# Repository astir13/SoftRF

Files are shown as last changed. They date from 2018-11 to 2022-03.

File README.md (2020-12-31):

# SoftRF 
Multifunctional DIY IoT-based general aviation proximity awareness system, forked from http://github.com/lyusupov/SoftRF. This fork only supports the prime mkII hardware and provides some extra modifications to allow for following features:

# Features on top of SoftRF prime mkII
* external 12V powered (has a power supply)
* external equipment connected through 9-pin D-Sub connector
* power switch management that allows power control operation even if the SoftRF is hidden behind the instrument panel
* auto power off when on ground and no external power supplied
* supports NMEA devices like Flarm LED/LX devices through RS-232

# Documentation
* [User Manual](https://github.com/astir13/SoftRF/tree/master/documents/usermanual/binaries)
* Software
    * Firmware
        * [Binary Releases](https://github.com/astir13/SoftRF/wiki/Updates)
        * [Source](https://github.com/astir13/SoftRF/tree/master/software/firmware/source)
* Hardware
You need:
    * 1x TT-GO T-Beam v1.1 board with OLED display, like https://www.aliexpress.com/item/33050391850.html?spm=a2g0s.9042311.0.0.27424c4dU9WiWD
    * 1x RS-232/UART converter, like https://www.aliexpress.com/item/4000189810712.html?spm=a2g0s.9042311.0.0.27424c4dQ6D88f
    * 1x DC-DC 12V to 5V/3A converter as power supply, like https://www.aliexpress.com/item/32826540392.html?spm=a2g0s.9042311.0.0.27424c4dbbq0Ht
    * a chassis, 3D printed: https://www.thingiverse.com/thing:4704154/
    * some hot-glue to fix wires and components on the T-beam to be more vibration resistant in the aviation environment
    * 4 small plastc screws
    * some wires
    * a protected Li-Ion battery, size 18650, 2600mAh or better, with integrated battery management system to give added security
    * a 9-pin sub-d female and male connector for soldering with matching srews to secure the corresponding counterpart with
    * a power ON-OFF-(ON) switch, like MS500D from Myiama Parts, e.g. https://www.reichelt.de/kippschalter-6a-125vac-1x-ein-aus-ein--ms-500d-p13156.html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
* Extras
    * see https://github.com/lyusupov/SoftRF

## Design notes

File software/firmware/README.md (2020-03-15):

## WebUI



## License

Copyright (C) 2016-2020 Linar Yusupov <linar.r.yusupov@gmail.com>

This program is free software: you can redistribute it and/or modify
it under the terms of the GNU General Public License as published by
the Free Software Foundation, either version 3 of the License, or
(at your option) any later version.

This program is distributed in the hope that it will be useful,
but WITHOUT ANY WARRANTY; without even the implied warranty of
MERCHANTABILITY or FITNESS FOR A PARTICULAR PURPOSE.  See the
GNU General Public License for more details.

You should have received a copy of the GNU General Public License
along with this program.  If not, see <http://www.gnu.org/licenses/>.

## Credits

 * Arduino core for ESP8266 is developed/supported by **ESP8266 Community** (support-esp8266@esp8266.com)
 * AVR/Arduino nRF905 Library/Driver is developed by **Zak Kemble**, contact@zakkemble.co.uk
 * flarm_decode is developed by **Stanislaw Pusep**, http://github.com/creaktive
 * Arduino Time Library is developed by **Paul Stoffregen**, http://github.com/PaulStoffregen
 * "Aircraft" and MAVLink Libraries are developed by **Andy Little**
 * TinyGPS++ and PString Libraries are developed by **Mikal Hart**
 * Adafruit NeoPixel Library is developed by **Phil Burgess**, **Michael Miller** and others
 * TrueRandom Library is developed by **Peter Knight**
 * IBM LMIC framework is maintained by **Matthijs Kooijman**
 * ESP8266FtpServer is developed by **David Paiva**
 * Lib_crc is developed by **Lammert Bies**
 * OGN library is developed by **Pawel Jalocha**
 * NMEA library is developed by **Timur Sinitsyn**, **Tobias Simon**, **Ferry Huberts**
 * ADS-B encoder C++ library is developed by **yangbinbin** (yangbinbin_ytu@163.com)
 * Arduino Core for ESP32 is developed by **Hristo Gochkov**
 * Adafruit BMP085 library is developed by **Limor Fried** and **Ladyada**
 * Adafruit BMP280 library is developed by **Kevin Townsend**
 * Adafruit MPL3115A2 library is developed by **Limor Fried** and **Kevin Townsend**
 * U8g2 monochrome LCD, OLED and eInk library is developed by **Oliver Kraus**
 * NeoPixelBus library is developed by **Michael Miller**
 * jQuery library is developed by **JS Foundation**
 * EGM96 data is developed by **XCSoar team**
 * BCM2835 C library is developed by **Mike McCauley**
 * SimpleNetwork library is developed by **Dario Longobardi**
 * ArduinoJson library is developed by **Benoit Blanchon**
 * Flashrom library is part of the **flashrom.org project**
 * Arduino Core for TI CC13X0 is developed by **Energia team**
 * EasyLink library is developed by **Robert Wessels** and **Tony Cave**
 * Dump978 library is developed by **Oliver Jowett**
 * FEC library is developed by **Phil Karn**
 * AXP20X, BMA423, FT5206 and PCF8563 libraries are developed by **Lewis He**
 * GxEPD2 library is developed by **Jean-Marc Zingg**
 * Adafruit SSD1306 and GFX libraries are developed by **Adafruit Industries**
 * GDL90 decoder is developed by **Ryan David**
 * Sqlite3 Arduino library for ESP32 is developed by **Arundale Ramanathan**
 * FLN/OGN aircrafts data is courtesy of **FlarmNet/GliderNet**
 * ESP32 I2S WAV player example is developed by **Tuan Nha**
 * AceButton library is developed by **Brian Park**
 * Arduino Core for STM32 is developed by **Frederic Pillon**
 * Python IGC format encoder is developed by **Tobias Bieniek**
 * port of MicroPython for ESP32 is developed by **Boris Lovosevic**
 * ESP32 BT SPP library is developed by **Evandro Copercini**
 * TFT library is developed by **Bodmer**

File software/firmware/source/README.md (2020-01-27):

# SoftRF firmware build instructions

[NodeMCU](https://github.com/lyusupov/SoftRF/tree/master/software/firmware/source#nodemcu)<br>
[ESP32](https://github.com/lyusupov/SoftRF/tree/master/software/firmware/source#esp32)<br>
[Raspberry Pi](https://github.com/lyusupov/SoftRF/tree/master/software/firmware/source#raspberry-pi)<br>
[CC13XX](https://github.com/lyusupov/SoftRF/tree/master/software/firmware/source#cc13xx)<br>
[STM32](https://github.com/lyusupov/SoftRF/tree/master/software/firmware/source#stm32)<br>

<br>

## NodeMCU

1. Follow [these official instructions](https://github.com/esp8266/Arduino#installing-with-boards-manager)
  to install Arduino IDE and latest Arduino ESP8266 Core
2. Become familiar with IDE and **NodeMCU** by building and uploading of a basic **Blink** sketch:<br>

    _File_ -> _Examples_ -> _ESP8266_ -> _Blink_ <br>

    then<br>

    _Sketch_ -> _Upload_

3. When you are done with the lesson, close your **Arduino** application
4. open ``<My Documents>`` (Windows) or ``<Home>`` (Linux) directory
5. create **Arduino** sub-directory
6. transfer full content of **SoftRF** and **libraries** GitHub folders into the sub-directory:

    [SoftRF](https://github.com/lyusupov/SoftRF/tree/master/software/firmware/source/SoftRF) &nbsp;&nbsp;**-->** ``<My Documents>``/Arduino/SoftRF <br>
    [libraries](https://github.com/lyusupov/SoftRF/tree/master/software/firmware/source/libraries) **-->** ``<My Documents>``/Arduino/libraries <br>

7. start **Arduino** application again
8. open **SoftRF** sketch from _File_ -> _Open_ menu
9. Select _Tools_ -> _Board_ -> _NodeMCU_ _1.0_
10. in _Tools_ -> _lwIP Variant_  -> _v2 Higher Bandwidth_
11. _Sketch_ -> _Upload_

## ESP32

1. Follow [these official instructions](https://github.com/espressif/arduino-esp32/blob/master/docs/arduino-ide/boards_manager.md)
  to install Arduino IDE and [latest **stable** Arduino ESP32 Core](https://github.com/espressif/arduino-esp32/releases/tag/1.0.4) (1.0.4)
2. Become familiar with IDE and **DoIt ESP32 DevKit** by building and uploading of a basic **Blink** sketch:<br>
```
int ledPin = 2; // use pin 14 for TTGO T-Beam rev.05 or higher   

void setup()
{
    pinMode(ledPin, OUTPUT);
    Serial.begin(115200);
}

void loop()
{
    Serial.println("Hello, world!");
    digitalWrite(ledPin, HIGH);
    delay(500);
    digitalWrite(ledPin, LOW);
    delay(500);
}
```

3. When you are done with the lesson, close your **Arduino** application
4. open ``<My Documents>`` (Windows) or ``<Home>`` (Linux) directory
5. create **Arduino** sub-directory
6. transfer full content of **SoftRF** and **libraries** GitHub folders into the sub-directory:

    [SoftRF](https://github.com/lyusupov/SoftRF/tree/master/software/firmware/source/SoftRF) &nbsp;&nbsp;**-->** ``<My Documents>``/Arduino/SoftRF <br>
    [libraries](https://github.com/lyusupov/SoftRF/tree/master/software/firmware/source/libraries) **-->** ``<My Documents>``/Arduino/libraries <br>

<!-- 7. take **libbt.a** binary from [this location](https://github.com/lyusupov/SoftRF/tree/master/software/firmware/binaries/ESP32/misc)<br>
    and overwrite existing one in ``<My Documents>``/Arduino/hardware/espressif/esp32/tools/sdk/lib -->
7. start **Arduino** application again
8. open **SoftRF** sketch from _File_ -> _Open_ menu
9. Select _Tools_ -> _Board_ ->  _ESP32_ _Dev_ _Module_
10. Select _Tools_ -> _Flash_ _Mode_ ->  _DIO_
11. Select _Tools_ -> _Flash_ _Size_ ->  _4MB_
12. Select _Tools_ -> _Partition_ _Scheme_ ->  _Minimal_ _SPIFFS_
13. Select _Tools_ -> _Flash_ _Frequency_ ->  _80MHz_
14. Select _Tools_ -> _CPU_ _Frequency_ ->  _80MHz_
15. Select _Tools_ -> _PSRAM_ ->  _Enabled_
16. _Sketch_ -> _Upload_

<br>

## Raspberry Pi

Although CLI application's source code for Raspberry Edition is located [at the same place](https://github.com/lyusupov/SoftRF/tree/master/software/firmware/source)<br> 
and is shared with other SoftRF platforms - build instructions for the code are different.

This build has to be done on a Raspberry Pi host.<br>
A known good Raspbian OS version that fits for this purpose is "Stretch".<br>
Make sure that basic development packages (such as: binutils, g++, GNU make & etc) are installed.<br>

1. transfer full content of **SoftRF** and **libraries** GitHub folders into a temporary build directory:

    [SoftRF](https://github.com/lyusupov/SoftRF/tree/master/software/firmware/source/SoftRF) &nbsp;&nbsp;**-->** ``<your path>``/SoftRF <br>
    [libraries](https://github.com/lyusupov/SoftRF/tree/master/software/firmware/source/libraries) **-->** ``<your path>``/libraries <br>

2. change directory on ``<your path>``/SoftRF and execute **make** as follows:<br>

```
pi@raspberrypi: $ make -f Makefile.RPi
(cd ../libraries/bcm2835/src/../ ; ./configure ; make)
checking for a BSD-compatible install... /usr/bin/install -c
checking whether build environment is sane... yes
checking for a thread-safe mkdir -p... /bin/mkdir -p
checking for gawk... no

< ... skipped ... >
```

As a result of the build, two program binaries will become created:
- **SoftRF** - the program code designed to work with Raspberry Pi's primary SPI bus (SPI 0);
- **SoftRF-aux** - the same program but to run over auxiliary SPI bus (SPI 1).

<br>

## CC13XX

The firmware is to be built on a Linux x86_64 host.<br>
[Energia](http://energia.nu/download/) IDE has to be pre-installed first.<br>

1. open ``<Home>`` directory
2. create **Energia** sub-directory
3. transfer full content of **UATbridge**, **SoftRF** and **libraries** GitHub folders into the sub-directory:

    [UATbridge](https://github.com/lyusupov/SoftRF/tree/master/software/firmware/source/UATbridge) **-->** ``<Home>``/Energia/UATbridge <br>
    [SoftRF](https://github.com/lyusupov/SoftRF/tree/master/software/firmware/source/SoftRF) &nbsp;&nbsp;&nbsp;&nbsp;&nbsp;&nbsp;**-->** ``<Home>``/Energia/SoftRF <br>
    [libraries](https://github.com/lyusupov/SoftRF/tree/master/software/firmware/source/libraries) &nbsp;&nbsp;&nbsp;&nbsp;**-->** ``<Home>``/Energia/libraries <br>

4. change directory on ``<Home>``/Energia/UATbridge
5. create all necessary symbolic links by doing **make links**:

```
$ make links
Creating symlink Platform_CC13XX.cpp  -->  ../SoftRF/Platform_CC13XX.cpp
Creating symlink SoCHelper.cpp  -->  ../SoftRF/SoCHelper.cpp
Creating symlink RFHelper.cpp  -->  ../SoftRF/RFHelper.cpp
Creating symlink GNSSHelper.cpp  -->  ../SoftRF/GNSSHelper.cpp

< ... skipped ... >
```

6. start **Energia** application
7. open **UATbridge** sketch from _File_ -> _Open_ menu
8. [install support](http://energia.nu/guide/boards/) for TI CC13XX familiy with _Tools_ -> _Board_ ->  _Boards_ _Manager..._
9. Select _Tools_ -> _Board_ ->  _LaunchPad_ _w/_ _CC1310_ _EMT_ _(48MHz)_
10. Select _Tools_ -> _Port_ ->  ``<your XDS110 port device name>``
11. Select _Tools_ -> _Programmer_ ->  _dslite_
12. try to build and upload using _Sketch_ -> _Upload_

12a. or, to build the firmware using shell prompt, do:

```
$ make build
energia --verify --verbose-build UATbridge.ino
Picked up JAVA_TOOL_OPTIONS:
Loading configuration...
Initializing packages...
Preparing boards...
Verifying...

< ... skipped ... >
```

13a. inspect **/tmp** directory and sub-folders, take **UATbridge.ino.elf** file and use it with TI's **Uniflash** or **Flash Programmer 2**.<br>

14a. (Optional) if you want to use [**cc2538-bsl.py**](https://github.com/JelmerT/cc2538-bsl) tool to put the firmware into flash memory of CC1310 IC via **boot loader**, run **make ihex**:

```
$ make ihex

< ... skipped ... >
``` 

<br>

## STM32

The firmware is to be built on a Linux x86_64 host.<br>
You can try to build it under Windows but you will have to manually set all the file links in this case.<br>
You will also need to get and connect ST-LINK/V2 USB adapter in order to put the firmware into your hardware's flash memory.<br>

1. Follow [these official instructions](https://github.com/stm32duino/wiki/wiki/Getting-Started)
  to install Arduino IDE and [latest **stable** Arduino STM32 Core](https://github.com/stm32duino/Arduino_Core_STM32/releases/tag/1.8.0) (1.8.0)
2. open ``<Home>`` directory
3. create **Arduino** sub-directory
4. transfer full content of **Retro**, **SoftRF** and **libraries** GitHub folders into the sub-directory:

    [Retro](https://github.com/lyusupov/SoftRF/tree/master/software/firmware/source/Retro) &nbsp;&nbsp;&nbsp;**-->** ``<Home>``/Arduino/Retro <br>
    [SoftRF](https://github.com/lyusupov/SoftRF/tree/master/software/firmware/source/SoftRF) &nbsp;&nbsp;**-->** ``<Home>``/Arduino/SoftRF <br>
    [libraries](https://github.com/lyusupov/SoftRF/tree/master/software/firmware/source/libraries) **-->** ``<Home>``/Arduino/libraries <br>
5. change directory on ``<Home>``/Arduino/Retro
6. create all necessary symbolic links by doing **make links**:

```
$ make links
Creating symlink Platform_STM32.cpp  -->  ../SoftRF/Platform_STM32.cpp
Creating symlink SoCHelper.cpp  -->  ../SoftRF/SoCHelper.cpp
Creating symlink RFHelper.cpp  -->  ../SoftRF/RFHelper.cpp
Creating symlink GNSSHelper.cpp  -->  ../SoftRF/GNSSHelper.cpp

< ... skipped ... >
```

7. start **Arduino** application
8. open **Retro** sketch from _File_ -> _Open_ menu
9. For S76G:<br>
    &nbsp;&nbsp;&nbsp;&nbsp;&nbsp;&nbsp;Select _Tools_ -> _Board_ ->  _Nucleo_64_<br>
    &nbsp;&nbsp;&nbsp;&nbsp;&nbsp;&nbsp;Select _Tools_ -> _Optimize_ ->  _Fast_ _(-O1)_<br>
    &nbsp;&nbsp;&nbsp;&nbsp;&nbsp;&nbsp;Select _Tools_ -> _Board_ _part_ _number_ ->  _Nucleo_ _L073RZ_<br>
    For STM32F103C8 "Blue Pill":<br>
    &nbsp;&nbsp;&nbsp;&nbsp;&nbsp;&nbsp;Select _Tools_ -> _Board_ ->  _Generic_ _STM32F1_ _series_<br>
    &nbsp;&nbsp;&nbsp;&nbsp;&nbsp;&nbsp;Select _Tools_ -> _Optimize_ ->  _Smallest_ _(-Os_ _default)_<br>
    &nbsp;&nbsp;&nbsp;&nbsp;&nbsp;&nbsp;Select _Tools_ -> _Board_ _part_ _number_ ->  _BluePill_ _F103C8_ _(128k)_<br>
10. Select _Tools_ -> _C_ _Runtime_ _library_ ->  _Newlib_ _Nano_ _(default)_
11. Select _Tools_ -> _USB_ _speed_ _(if available)_ ->  _Low/Full_ _Speed_
12. For S76G "Dongle":<br>
    &nbsp;&nbsp;&nbsp;&nbsp;&nbsp;&nbsp;Select _Tools_ -> _USB_ _support_ _(if available)_ ->  _CDC_ _(generic_ _'Serial'_ _supersede_ _U(S)ART)_<br>
    &nbsp;&nbsp;&nbsp;&nbsp;&nbsp;&nbsp;Select _Tools_ -> _U(S)ART_ _support_ ->  _Enabled_ _(no_ _generic_ _'Serial')_<br>
    &nbsp;&nbsp;&nbsp;&nbsp;&nbsp;&nbsp;Select _Tools_ -> _Upload_ _method_ ->  _STM32CubeProgrammer_ _(DFU)_<br>
    &nbsp;&nbsp;&nbsp;&nbsp;&nbsp;&nbsp;Select _Tools_ -> _Port_ ->  ``<your Dongle's DFU device name>``<br>
    For S76G "SkyWatch" or STM32F103C8 "Blue Pill":<br>
    &nbsp;&nbsp;&nbsp;&nbsp;&nbsp;&nbsp;Select _Tools_ -> _USB_ _support_ _(if available)_ ->  _CDC_ _(no_ _generic_ _'Serial')_<br>
    &nbsp;&nbsp;&nbsp;&nbsp;&nbsp;&nbsp;Select _Tools_ -> _U(S)ART_ _support_ ->  _Enabled_ _(generic_ _'Serial')_<br>
    &nbsp;&nbsp;&nbsp;&nbsp;&nbsp;&nbsp;Select _Tools_ -> _Upload_ _method_ ->  _STM32CubeProgrammer_ _(SWD)_<br>
    &nbsp;&nbsp;&nbsp;&nbsp;&nbsp;&nbsp;Select _Tools_ -> _Port_ ->  ``<your ST-LINK/V2 port device name>``<br>
13. try to build and upload using _Sketch_ -> _Upload_

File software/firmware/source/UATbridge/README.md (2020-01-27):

## UAT Bridge

This folder contains source code of **UAT Bridge** firmware for Texas Instruments CC1310 RF SoC. <sup>1</sup><br>
The code is essential part of [SoftRF project](https://github.com/lyusupov/SoftRF).<br>

<sup>1</sup> - _mass production of CC1312R IC (direct successor of CC1310) is scheduled by TI on Q1 of 2019_.<br>
&nbsp;&nbsp;&nbsp; _Announced specs of the CC1312R are promising to make **1090ES** <sub>(worldwide ADS-B standard)</sub> reception possible as well_.<br>

## Purpose

Primary purpose of the **UAT bridge** is to receive ADS-B traffic information on UAT (978 MHz) aviation frequency,<br>
then to re-broadcast the data using one of supported RF ISM band protocols.<br>

For the list of the ISM protocols, please, read [SoftRF specs](https://github.com/lyusupov/SoftRF#compatibility-1).<br>

Traffic information is re-broadcasted at very low power setting, so reception coverage is limited to a close vicinity of
the aircraft, equipped with the **UAT Bridge**. Other aircrafts nearby, such as gliders on the grid, have a chance to receive the information as well.<br>  

The "**bridge**" is one-way only. No re-broadcasting from ISM band into aviation band (UAT) is allowed. Thus, it does **not** transmit anything on 978 MHz.<br>

For the benefit of most of pilots, **receiving device is not necessarily has to be one of [SoftRF](https://github.com/lyusupov/SoftRF) units**.<br>
Other make and models, such as SkyTraxx, OGN Tracker, PilotAware or FLARM should suffice.<br> 

## Hardware

DIY **UAT bridge** hardware consists of:
1. [SoftRF-UAT](https://github.com/lyusupov/UAT-test-signal#variant-2-advanced) main board, and
2. [SoftRF-LoRa](https://github.com/lyusupov/SoftRF/wiki/SoftRF-LoRa-module) daughterboard.

<br>
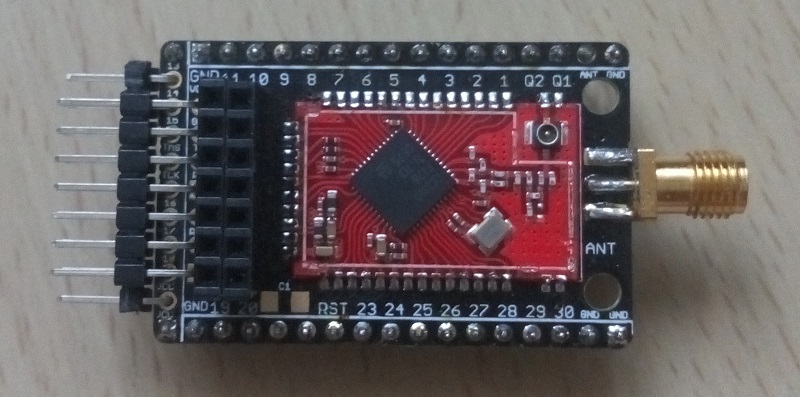
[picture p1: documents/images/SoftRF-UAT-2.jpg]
<br>
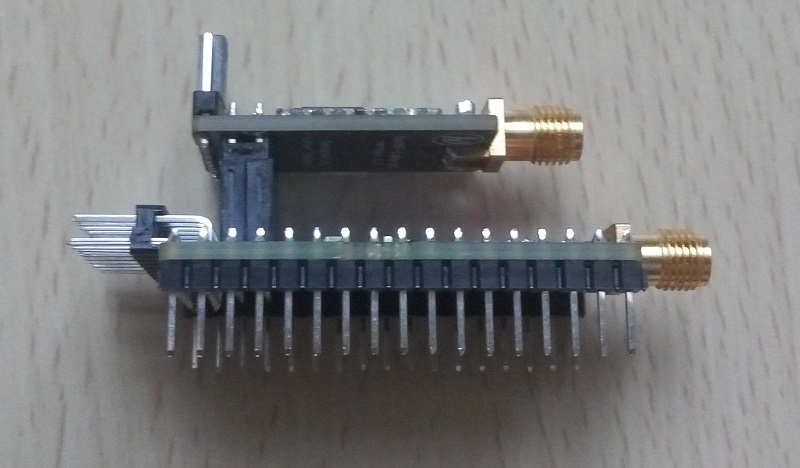
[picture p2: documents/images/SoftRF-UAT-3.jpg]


## Alternative use

The firmware auto-senses presence of connected [SoftRF-LoRa](https://github.com/lyusupov/SoftRF/wiki/SoftRF-LoRa-module) daughterboard.<br>
When the daughterboard is not attached - remaining [SoftRF-UAT](https://github.com/lyusupov/UAT-test-signal#variant-2-advanced) board fallbacks into **UAT Receiver** operation mode automatically.<br>

**UAT Receiver** makes reception of UAT signals, then transmits serial data frames over UART @ 2 Mbps.<br>
This data rate and format of the frames were choosen to be compatible with [Stratux UATRadio, Low Power v3](https://www.amazon.com/dp/B07JNSHCLQ/).

## Build instructions

To build firmware binary from source code, please, follow [these instructions](https://github.com/lyusupov/SoftRF/tree/master/software/firmware/source#cc13xx).

## Validation

Reception capability of the **UAT Receiver** mode was validated both with:

1. **SoftRF WebUI** on ESP32:

<br>

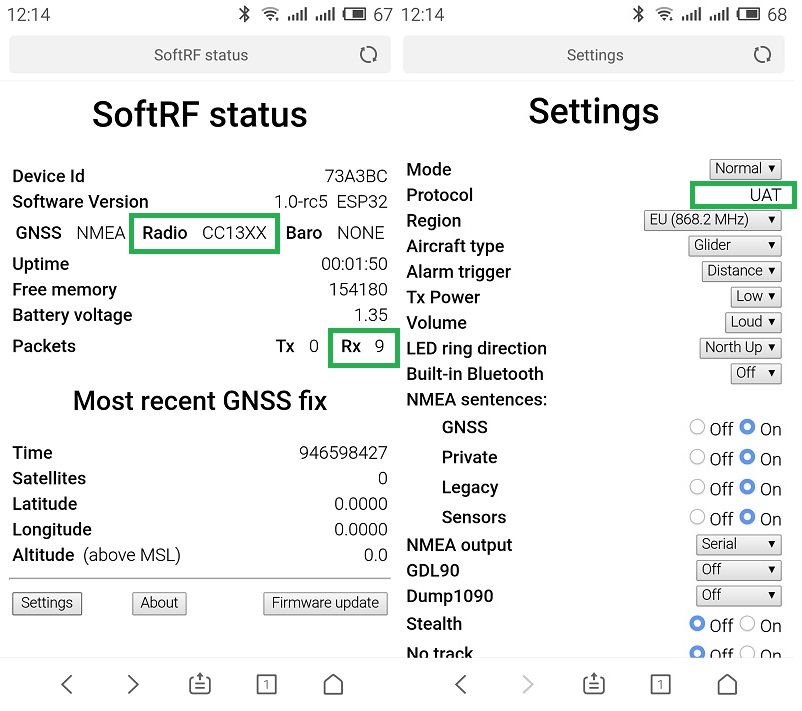
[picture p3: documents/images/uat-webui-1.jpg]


<br>

2. and genuine [**Stratux**](http://stratux.me/) software on a Raspberry Pi:

<br>

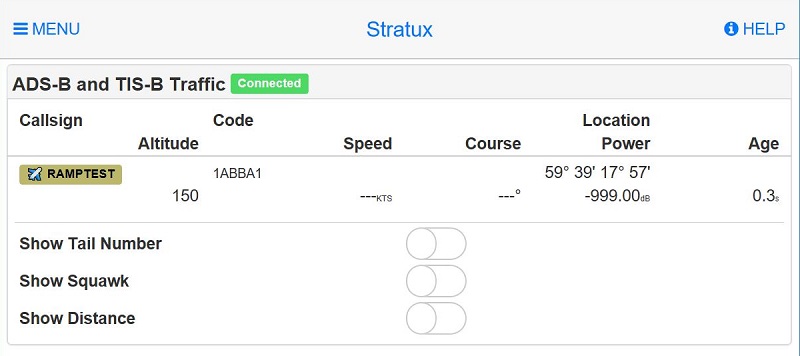
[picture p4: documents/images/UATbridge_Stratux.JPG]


## Known limitations

1. reception of UAT signals is currently limited to "downlink" (air-to-air) packets only. So, realtime weather and other "bells and whistles" of the UAT protocol are not available ;
2. due to limited maximum speed of ESP8266's UART, this platform is not able to use **UAT receiver** right now. ESP32 and Raspberry Pi are Ok ;
3. RF settings of CC1310 IC are not optimal yet. This causes average 10-20% packets loss ratio at this time ;
4. "Stock" EByte E70 module has built-in passive HF filter to meet FCC compliance. Because of that, sensitivity @ 978 MHz is reduced by 10-15 dB. To achieve full performance, you need to open the shield and solder a bypass.

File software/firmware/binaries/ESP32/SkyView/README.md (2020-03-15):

## Release notes

### revision 0.10

#### New features

- Bluetooth SPP and LE connection methods. Mostly applicable for a 'SoftRF on ESP32' partner - other devices may or may not work ;
- serial data input over EZ built-in micro-USB port ;
- one more radar view's zoom level ;
- 'Wi-Fi off' timer option ;
- traffic filter (by altitude) ;
- team member's aircraft (if any) is depicted in a bit different manner ;
- dual boot option ( demo application is [iArradio](https://github.com/TioRuben/iArradio) ).

#### Known issues and limitations

- same as in 0.9, plus
- first Bluetooth SPP connection may cause restart of a partner SoftRF data source device ;
- due to high RAM memory usage, Bluetooth SPP may coexist with either voice or aircraft's data option but not both ;
- only Bluetooth 'Simple Pairing' (no key) method is currently supported.

#### Flashing instructions

&nbsp;&nbsp;&nbsp;&nbsp;**Regular:**<br>
&nbsp;&nbsp;&nbsp;&nbsp;&nbsp;&nbsp;&nbsp;&nbsp;&nbsp;&nbsp;&nbsp;&nbsp;'Web Update' UI feature does not work in previous 0.9 revision. Use generic ('cable') method instead.<br>
&nbsp;&nbsp;&nbsp;&nbsp;&nbsp;&nbsp;&nbsp;&nbsp;&nbsp;&nbsp;&nbsp;&nbsp;Follow **Step 1** and **Step 2** of this [**Quick start**](https://github.com/lyusupov/SoftRF/wiki/SkyView.-Quick-start) guidance.

&nbsp;&nbsp;&nbsp;&nbsp;**Dual boot:**<br>
&nbsp;&nbsp;&nbsp;&nbsp;&nbsp;&nbsp;&nbsp;&nbsp;&nbsp;&nbsp;&nbsp;&nbsp;Follow [these instructions](https://github.com/lyusupov/SoftRF/wiki/SkyView.-Dual-boot).<br>
&nbsp;&nbsp;&nbsp;&nbsp;&nbsp;&nbsp;&nbsp;&nbsp;&nbsp;&nbsp;&nbsp;&nbsp;**NOTICE!**: [**iArradio**](https://github.com/TioRuben/iArradio) firmware that comes with it is a DEMO. I will reject your every claim or question.<br>
&nbsp;&nbsp;&nbsp;&nbsp;&nbsp;&nbsp;&nbsp;&nbsp;&nbsp;&nbsp;&nbsp;&nbsp;&nbsp;&nbsp;&nbsp;&nbsp;&nbsp;&nbsp;&nbsp;&nbsp;If you need a custom weather, playlist or timezone - build your own firmware file by yourself.<br>

### revision 0.9

#### Known issues and limitations

- maximum number of tracked objects is limited to 9 ;
- very short keypress may not work. Make a more distinct one ;
- keypress may not work when audio is playing ;
- view mode change may cause 2-3 seconds of '**NO DATA**' or '**NO FIX**' warning ;
- 'anti-ghosting' full screen refresh may cause 2-3 seconds of '**NO DATA**' or '**NO FIX**' warning ;
- '**NO DATA**' or '**NO FIX**' warning may appear right after voice traffic alert message ;
- **VOICE2** and **VOICE3** may have some WAV files missing ;
- Wi-Fi re-connect may fail sometimes. Reset of SoftRF server and/or SkyView client does typically help ;
- does not work with Stratux yet due to issues with DHCP leases and GDL90 data (over-)flow.

### revision 0.8

Very first deployment of SkyView's firmware binaries.

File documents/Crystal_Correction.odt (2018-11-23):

Howto correct the frequency of the nRF905 module

Author: sp@albatros-tech.eu, Stefan Pielmeier

Date: 2018-11-23

My nRF905 created a EU frequency that was 868.435 or 868.235 MHz.

The frequency error of the TX frequency was therefore 35kHz. That was way too much to achieve:

- beeing received by the OGN tracker

- beeing received by my other SoftRF (based on TTGO, which is 3.5kHz below correct frequency).

- receiving transmissions from other SoftRF

In order to correct the problem, I tried to correct the frequency in Software. However, that is not possible as the nRF905 chip is programmed by “band” and therefore does not allow fine tuning of the channel by smaller frequencies.

Additionally, the crystal on the nRF905 board is not voltage controlled. Therefore, manual tuning was chosen. The nRF905 board implements the crystal as shown in [1], pg. 2:

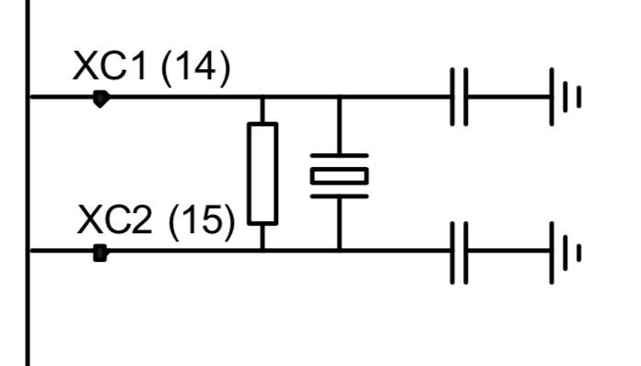
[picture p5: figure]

2 additional 4.7pF condesators are added in parallel to the 2 existing ones. Just solder them on top of the existing ones. Take approx. 5pF per 15kHz error in total.

So if your error is +30kHz, just add 2*4.7pF. If your error is +35kHz, add a bit more, etc.

There are limits for what can be achieved. The Crystal might eventually stop to swing as required if tuned too much.

Testing: implement an OGN receiver with a raspberry pi and RTL-SDR. These are frequency corrected by GSM signals (if available in your area) and can show the frequency error quite exactly.

A well calibrated frequency counter can also be connected to the antenna output with a 10dB attenuator to show the TX frequency. As the SoftRF only transmits while having proper GPS position, you need to esure that before measuring.

References:

[1] nRF905 chip datasheet, rev. 1.1, June 2004

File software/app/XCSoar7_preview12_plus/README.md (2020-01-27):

# Binary packages of XCSoar 7 "preview" with combined traffic view feature

## References:
1) [Genuine pull request](https://github.com/XCSoar/XCSoar/pull/63) ;
2) [Official XCSoar source code repository](https://github.com/XCSoar/XCSoar) ;
3) [Build tools](https://github.com/lordfolken/xcsoar-docker-build).

## Disclaimer
The packages are provided "AS IS". Any support or help requests will be rejected.<br>
If you have any issues with the binaries - [build them yourself](https://github.com/lordfolken/xcsoar-docker-build) or wait until official release date.

## Example

1) Two of SoftRF units are configured to operate with OGNTP and P3I protocols<br>
and deliver NMEA data over Bluetooth, as follows:

<br>

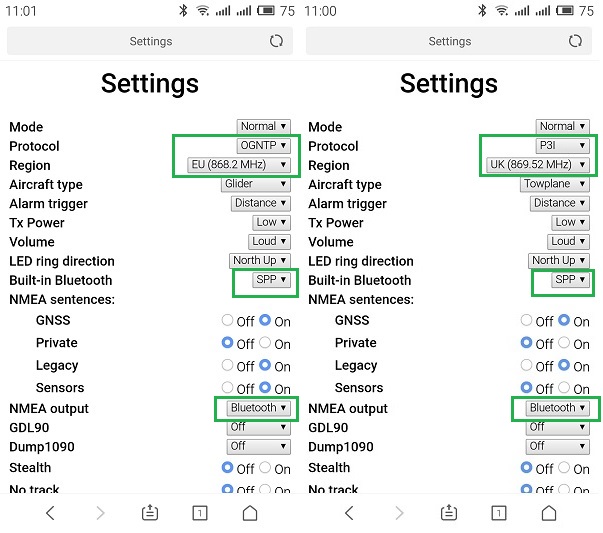
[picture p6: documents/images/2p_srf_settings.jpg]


2) XCSoar 7 boot time version information:

<br>

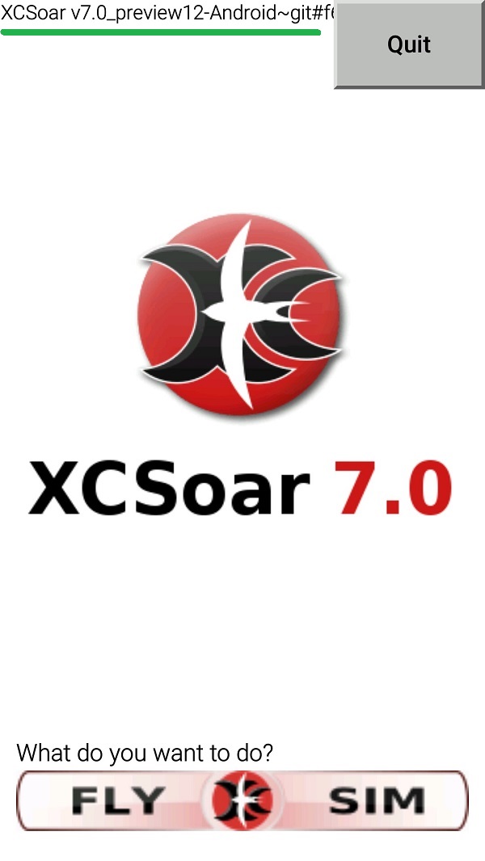
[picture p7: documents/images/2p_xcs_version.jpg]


<br>

3) XCSoar's "Device settings" menu:

<br>

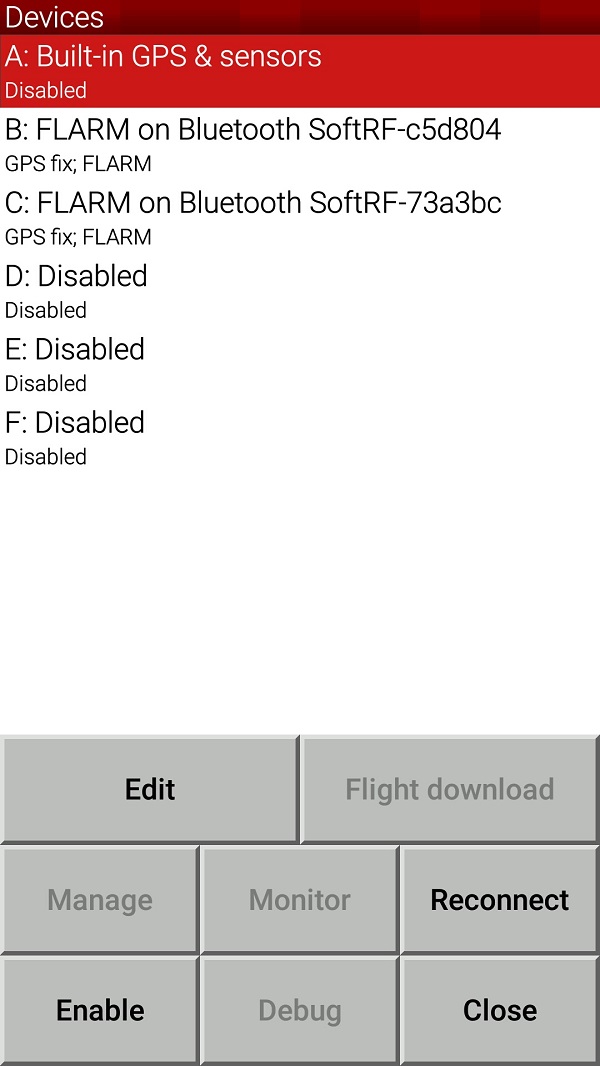
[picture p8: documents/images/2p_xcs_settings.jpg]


<br>

4) Presence of close P3I and OGNTP traffic is indicated on each of "Monitor" screens:

<br>

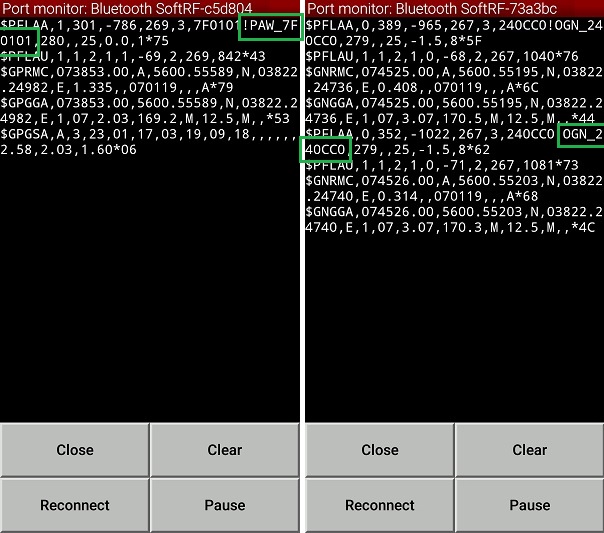
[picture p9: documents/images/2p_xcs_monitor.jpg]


<br>

5) The traffic is shown on "Moving Map" and "Radar" views:

<br>

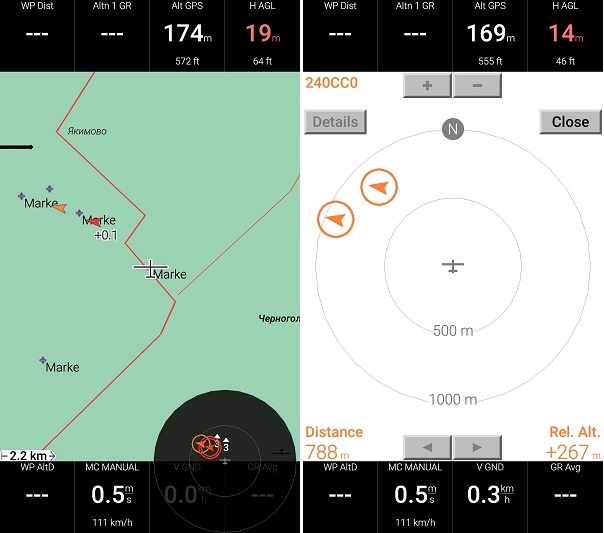
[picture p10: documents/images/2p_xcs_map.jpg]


<br>

6) As well as in the "Traffic List" :

<br>

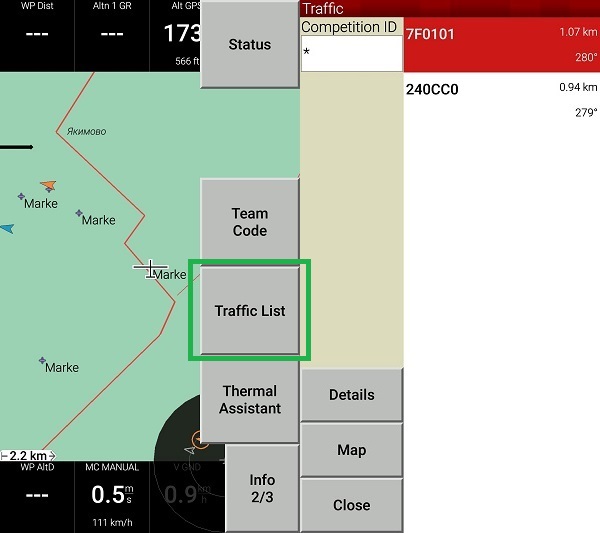
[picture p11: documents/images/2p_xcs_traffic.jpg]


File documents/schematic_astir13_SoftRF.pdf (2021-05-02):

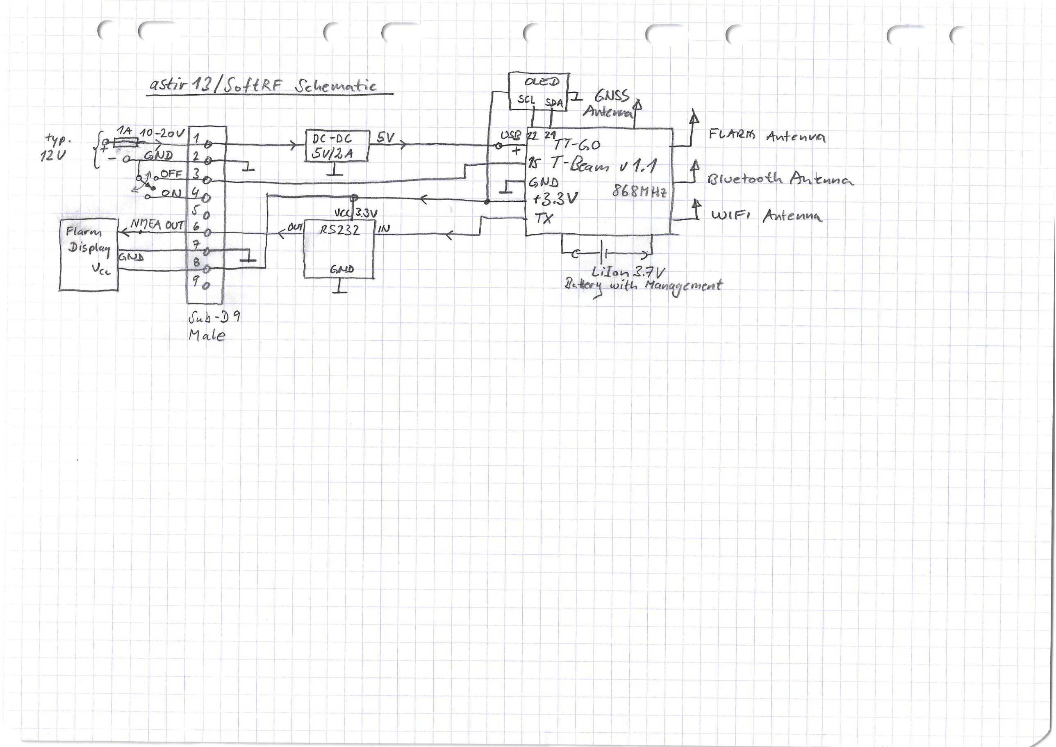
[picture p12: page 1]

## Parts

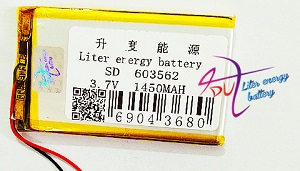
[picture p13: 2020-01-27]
documents/images/bom/lipo-1450.jpg

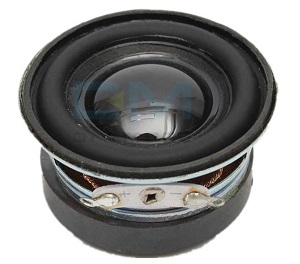
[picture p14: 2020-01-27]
documents/images/bom/speaker.jpg

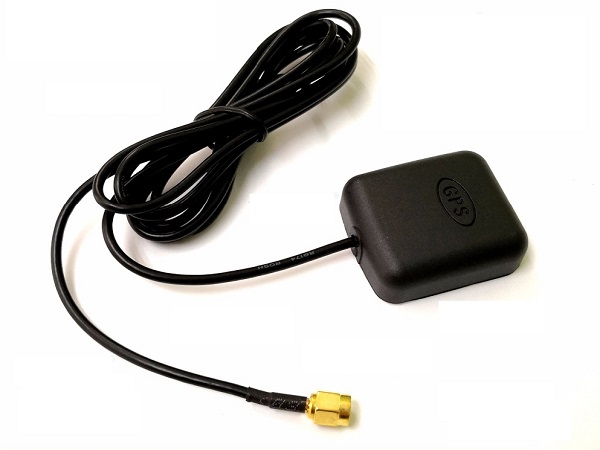
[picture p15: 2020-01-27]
documents/images/bom/gnss-antenna.jpg

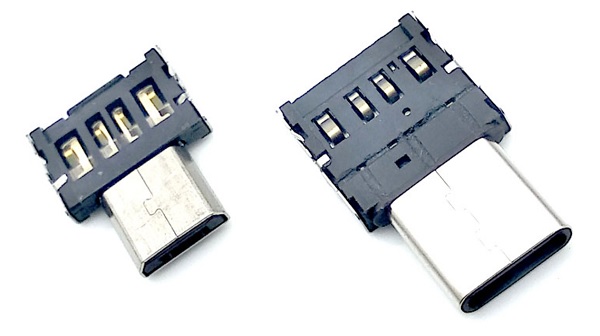
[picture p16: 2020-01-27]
documents/images/bom/musb-typec.jpg

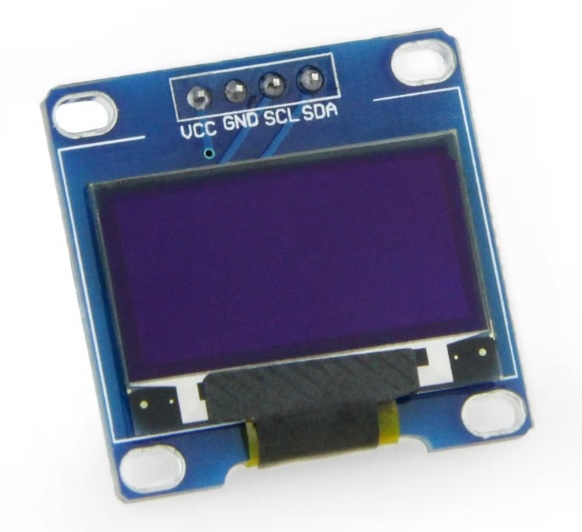
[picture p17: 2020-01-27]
documents/images/bom/oled-096.jpg

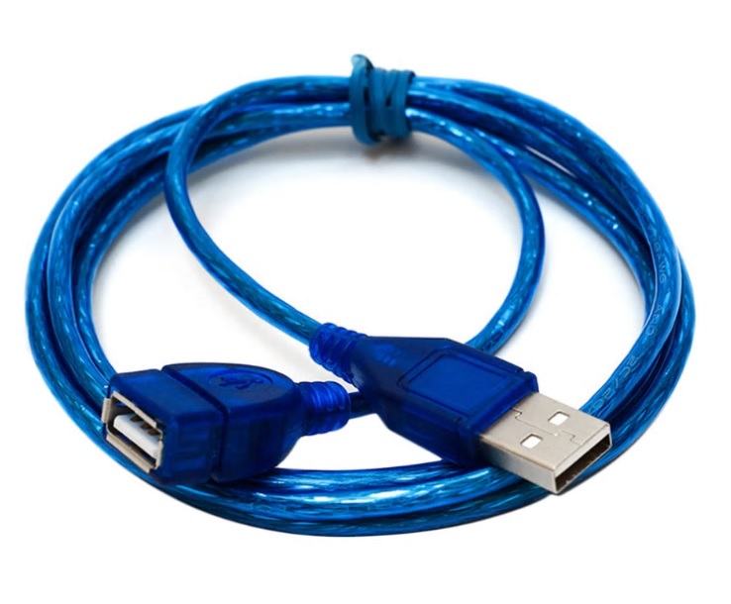
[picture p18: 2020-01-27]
documents/images/bom/usb-ext.jpg

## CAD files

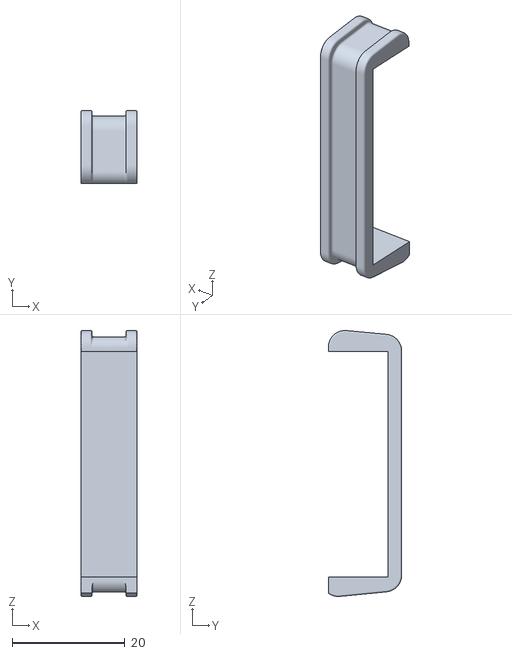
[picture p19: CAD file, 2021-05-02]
case/ogn_strip_case_holder.stl
10.0 x 13.0 x 47.2

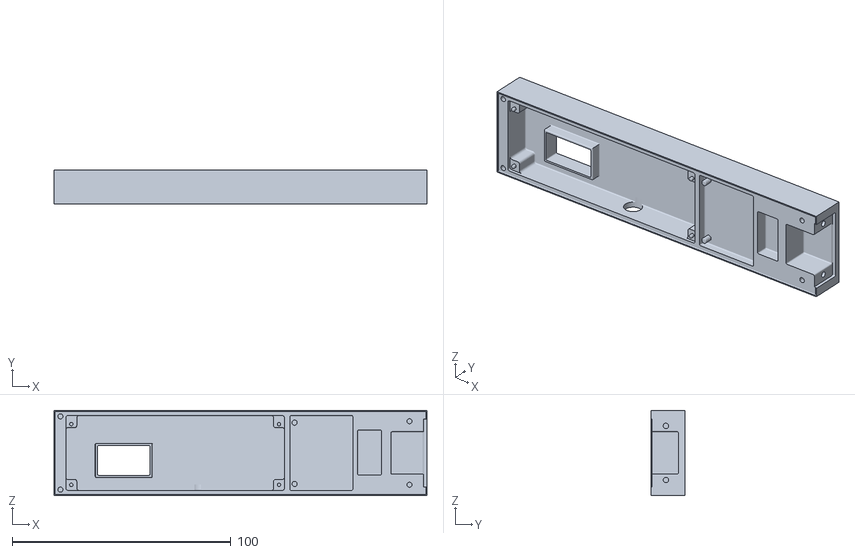
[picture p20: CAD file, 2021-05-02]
case/ogn_case_lid.stl
170.6 x 15.5 x 39.0

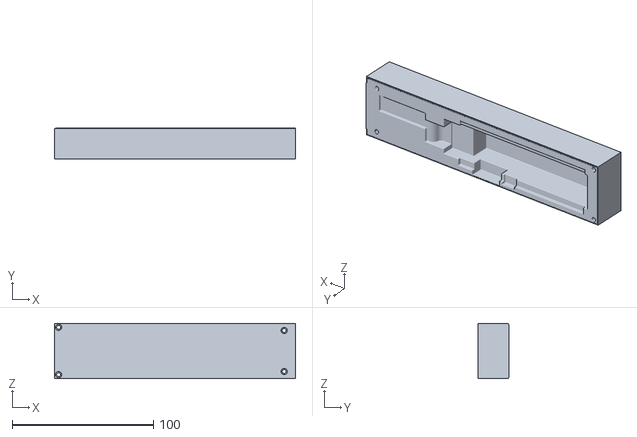
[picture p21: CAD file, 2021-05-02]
case/ogn_case_bottom.stl
170.6 x 22.0 x 39.0

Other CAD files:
case/Lilygo_TTGO_V1.1_case_v9.f3d

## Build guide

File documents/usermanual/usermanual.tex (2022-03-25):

\documentclass[11pt,a4paper]{article}
\usepackage[utf8]{inputenc}
\usepackage[english]{babel}
\usepackage{graphicx}  % include graphics
\usepackage{lastpage}  % number of pages in header
% \usepackage{pgffor}    % foreach
\usepackage{color}     % for colors
\usepackage{multirow}  % multiple rows in tables
% \usepackage{latexsym}  % for \Box
\usepackage{vhistory}		% supplies us with versionhistory\usepackage[hidelinks]{hyperref}   % references in pdf file
\usepackage[section]{placeins} % keep floats where they are inserted
\usepackage{fancyhdr} % the custom header
\setlength{\headheight}{12mm}
\pagestyle{fancy}
\fancyhf{} % remove everything
\usepackage[left=2.9cm,right=2.9cm,top=2.5cm,bottom=1.5cm]{geometry} % the page margins

\title{\Huge User Manual\\[5mm]\Large SoftRF (Github astir13/SoftRF fork)\\[5mm]matching SoftRF firmware version 1.3f}
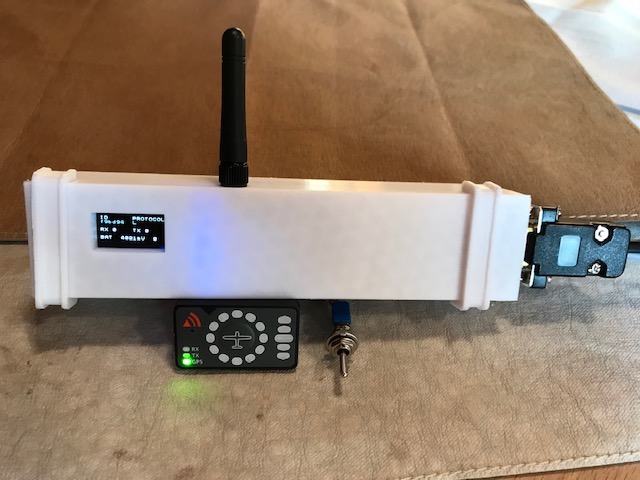
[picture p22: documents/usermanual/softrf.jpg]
\date{2022-03-25\\[10mm]Thanks to all contributrs of the Github SoftRF Project.\\[3cm]}
\begin{document}
% some defines
\definecolor{lightpink}{RGB}{229,172,197}
\definecolor{cadmiumred}{RGB}{230,0,38}

%titlepage
\maketitle
\newpage

% settings for the header
	\setlength{\unitlength}{1mm}
	\thicklines
	\newcommand{\graphwidth}{200}
	\newcommand{\graphheight}{11}
	\newcommand{\secondcolumnstart}{100}
	\newcommand{\secondcolumnstarttable}{\the\numexpr\secondcolumnstart - 4 mm}
	\newcommand{\bottomcalstart}{80}
	\newcommand{\bottomareastart}{60}

% the header
%\lhead{
%	\begin{tabular}{p{8cm}p{6cm}p{2.3cm}}
%	\large astir13 SoftRF & User Manual v. 1.3e rev. 0 & \hfill pg. \thepage 		(\pageref{LastPage})
%	\end{tabular}
%\begin{picture}(\graphwidth,\graphheight)
%	\put(0,\the\numexpr\graphheight){\line(1,0){\graphwidth}}
%	\put(0,\the\numexpr\graphheight - 5){\begin{tabular}{p{\the\numexpr\secondcolumnstarttable}p{6cm}}
%	\small Prepared by & \small Date/Context \\
%	\hspace{2cm}\Large Stefan Pielmeier & \hspace{2cm}\Large 2020-12-28 \\
%	\end{tabular}}
%	\put(0,\the\numexpr\graphheight - 10){\line(1,0){\graphwidth}}
%	\put(0,\the\numexpr\graphheight - 10){\line(0,1){10}}
%	\put(\secondcolumnstart,\the\numexpr\graphheight - 10){\line(0,1){10}}
%\end{picture}}
\lhead{astir13/SoftRF}
\chead{User Manual v.\/1.3f rev.\/0}
\rhead{pg. \thepage 		(\pageref{LastPage})}
\renewcommand{\headwidth}{17cm}
%\renewcommand{\headrulewidth}{0pt}

\section{Revision History}
\begin{versionhistory}
  \vhEntry{1.3e rev. 0}{2020-12-30}{astir13}{created from scratch}
  \vhEntry{1.3e rev. 1}{2020-12-31}{astir13}{editorials, added Display section, added Revision History, corrected links to fork}
  \vhEntry{1.3f rev. 0}{2022-03-25}{astir13}{autopower off at 50\% battery level, not after 10 minutes}
\end{versionhistory}

\section{Acronyms}
\begin{description}
\item[Baidu] The GNSS deployed by China
\item[FANET] another open anti-collision protocol
\item[FLARM] The protocol used by the equipment traded by the company Flarm; the term legacy is used in the SoftRF setup and display "L", to indicate that the SoftRF does not use the Flarm protocol, as it is private and may not be used; however, the SoftRF uses a protocol, that is understood by Flarm devices and can receive Flarm transmissions as of now.
\item[GLONASS] The GNSS deployed by the Russian Federation
\item[GNSS] Global Navigation Satellite System; this can be GPS but also Glonass, Baidu or Gallileo, dependent on the chipset on the SoftRF; current SoftRF use GLONASS and GPS
\item[GPS] Global Positioning System: the GNSS deployed by the USA
\item[Gallileo] The GNSS deployed by the European Union and ESA
\item[OGN] The open glider net, see http://wiki.glidernet.org/
\item[OGNTP] another open air traffic awareness protocol
\item[RS-232] the cable-based data line protocol used for the communication between SoftRF and other cockpit equipment like Flarm LED, LX Nav/LXNavigation flight computers and smart e-varios like EOS/ERA/S-80 or S-100.
\end{description}

\section{Disclaimer}
THIS DOCUMENT IS PROVIDED "AS IS", WITHOUT WARRANTY OF ANY KIND, EXPRESS OR IMPLIED, INCLUDING BUT NOT LIMITED TO THE WARRANTIES OF MERCHANTABILITY, FITNESS FOR A PARTICULAR PURPOSE AND NONINFRINGEMENT. IN NO EVENT SHALL THE AUTHORS OR COPYRIGHT HOLDERS BE LIABLE FOR ANY CLAIM, DAMAGES OR OTHER LIABILITY, WHETHER IN AN ACTION OF CONTRACT, TORT OR OTHERWISE, ARISING FROM, OUT OF OR IN CONNECTION WITH THE SOFTWARE OR THE USE OR OTHER DEALINGS IN THE SOFTWARE, DOCUMENTATION OR HARDWARE DESCRIBED HERE.

\section{Foreword}
The SoftRF based air traffic awareness devices use the ISM bands. The devices are good tools to aid pilot situational awareness by often giving successful information about the position, direction, vertical and horizontal speed of other aviation traffic. However, they are not to be trusted all times and in all situations. Do not trust your life to this information, and only trust your eyes for VFR flight anti-collision avoidance.

SoftRF, Flarm, FANET, OGN-Tracker, Pilot-Aware, Skytraxx use transmission and reception via the so-called ISM bands, which are used for many industrial, scientific and medical purposes. Thus, the used frequencies are not exclusively reserved for air traffic transmissions, and can be used for multiple other purposes, also on board of aircrafts. No frequency coordination/licensing is provided by the authorities in most countries, which is very convenient, but there also is no protection against interference from other equipment.

\begin{center}
\fbox{\parbox{12cm}{As a consequence of potential interference from other equipment using the same frequency bands, reception in your own installation or the installation in other planes can be impaired, leading to potential "ghost" traffic, or (worse) masking existing traffic away, i.e. "hiding" other traffic.}}
\end{center}

Therefore, you should never trust such installations, nor the fact that you can detect all other planes in your vicinity using these tools. Additionally, commercial planes and motorplanes rarely use these protocols, and there is no legal carrige requirement for such equipment.

The above statements are not true for certified Mode-S transponders and TCAS equipment. Air transponders operate on reserved frequencies, may only be operated when certified and properly tested, with about 1000 times higher transmit power, and are proved to work efficiently and effectively for sailplanes, small aeroplanes and commercial planes of all sizes. In the eyes of the author, certified transponder based communication is the future of air anti-collision for all segments, but in some countries you may not be allowed such equipment in small areoplanes, drones, ultralights, and so on. So the ISM band based air traffic awareness equipment might have a long future ahead.

A note on the protocol: While Flarm is the most used protocol, it is advised to consider using the other protocols like OGN-TP because they are open source. Flarm will, thanks to the Open Glider Net initiative, not change protocol anymore, because most pilots highly rely on the existence of the open glider network to track their planes safely throughout each journey. If Flarm would change the protocol one day, remember that you can change your SoftRF to use e.g. OGN-TP through the settings menu very easily, and all open glider Net trackers would be able to "see" your plane in real time again.

\section{Basics about SoftRF}
The SoftRF main purpose is to transmit anti-collision data to other devices. In order to do so, it finds information about the own aircraft and packages it into a protocol, which then is transmitted through the SoftRF antenna on UHF ISM band frequencies.

Following data is transmitted (example from legacy protocol (Flarm v6):
\begin{itemize}
\item your position (latitude and longitude),
\item the GPS status,
\item horizontal speed (speed over ground),
\item heading (over ground from GNSS),
\item vertical speed (climb or sink rate),
\item your identification,
\item the type of aircraft,
\item stealth mode (for competitions),
\item do not track information (opt-out from OGN).
\end{itemize}

The other purpose is to receive such transmissions from other aircrafts around you and to provide this information to your other cockpit devices to issue alerts and situational awareness. Other devices can be:

\begin{itemize}
\item Android tablet or phone with XCSoar App installed
\item Flarm LED
\item LXNavigation ERA/EOS 80 devices
\item LXNav S80/100 devices
\item larger Flight computer series from LXNavigation and LXNav, or self-built
\end{itemize}

From the point in time when the SoftRF has successful reception from GNSS, it is transmitting status and all received information over following interfaces if configured correctly:
\begin{itemize}
\item Bluetooth (used for mobile phone/tablet Apps like XCSoar)
\item NMEA cable based output (RS-232) at a speed of 38400 baud
\end{itemize}

\section{Installation}
The SoftRF has to be built into a stable case, secured against overheating, examples can be seen at https://github.com/lyusupov/SoftRF/tree/master/case.

For running the astir13 fork of the SoftRF firmware, some hardware additions are required that are described in the Wiki found at https://github.com/astir13/SoftRF/wiki.

\subsection{Mechanical}
Fasten the SoftRF case and all wirings tightly with other equipment behind the instrument cluster, i.e. using wire straps. As a rule of thumb, an installation shall be able to handle +/-10G, so if your SoftRF weights 200g, the installation shall sustain a 20N force, applied at the SoftRF in each direction.

The optional FlarmLED display shall be mounted securely into the instrument panel using screws, because the supplied adhesive tape is not sufficient, follow the instructions of the producer.

\begin{center}
\fbox{\parbox{12cm}{No mechanical installations may limit or change existing mechanical functions of the aircraft.}}
\end{center}

\subsection{SoftRF Antenna}
The golden SMA female connector of the SoftRF has to be connected to a matching SMA male connector leading the RF signal to the SoftRF antenna resonating in the band of your SoftRF's transmissions. If your SoftRF is deployed in the European Union, the frequency is $868.2$MHz, and the antenna shall be resonant on this frequency. You can mount the antenna directly onto the SoftRF case or connect the antenna through a $50 \Omega$ RF cable such as RG174 for lenghts $< 1$m. For cable lengths above 1m, good results can be achived using e.g. BELDEN RF 200 cable which at many places can be bought already fully configured with SMA connectors attached.

A well-proven design is a so-called ground plane antenna on top of the instrument cluster cover, like shown in Figure \ref{groundplane}.

\begin{figure}[h]
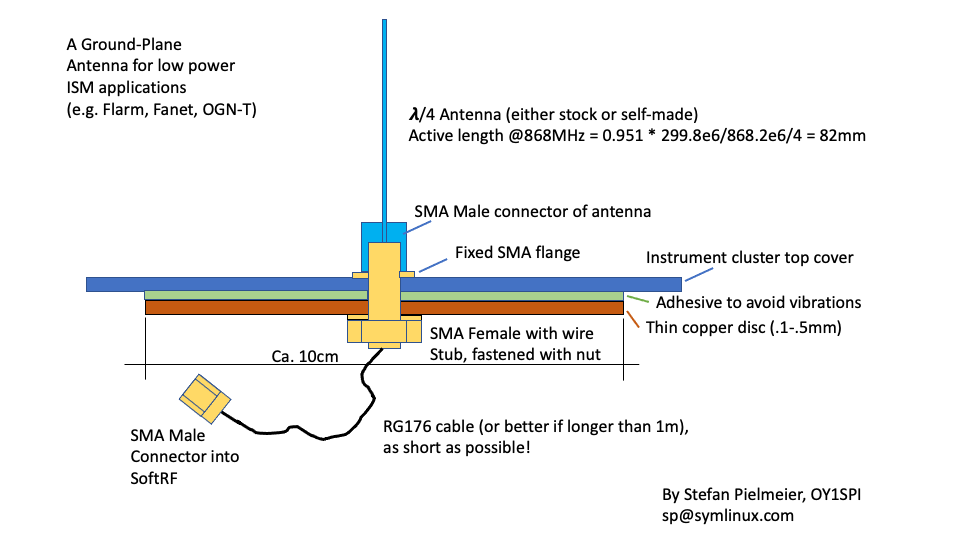
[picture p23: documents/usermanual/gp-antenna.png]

\caption{Example ground plane antenna construction that can be used for the SoftRF}\label{groundplane}
\end{figure}\FloatBarrier

Beware that there are many antennas out there that say they are Flarm compatible, but they might actually not be resonant at the required frequency. Before use, it might be relevant to test your antenna with an antenna tester to be sure it is resonant at the right frequencies. Suitable Antenna testers (e.g. Nano VNA from aliexpress) are owned by radio nerds like Amateur Radio girls and guys, find one to help you if you don't know anything about antennas, because this is an important part of achieving a good transmission range.

\subsection{GNSS Antenna}
The SoftRF needs a valid 3D position from a global navigation satellite system (GNSS), e.g. GPS or GLONASS, to define timing and the own aircraft's

\begin{itemize}
\item position,
\item altitude,
\item horizontal speed (speed over ground),
\item vertical speed (climb or decend), and
\item heading.
\end{itemize}

The GNSS antenna is integrated into the SoftRF case's top, just in the middle, see Figure \ref{fig_gnss_ant}. Therefore, the case shall be mounted with the SoftRF display to the side and the SoftRF golden antenna plug to the top, as close as possible to the instrument cluster top cover as possible. No metal parts shall obstruct the GNSS reception field above the SoftRF middle section, otherwise GNSS reception might be impaired. 

\begin{figure}[h]
\centering
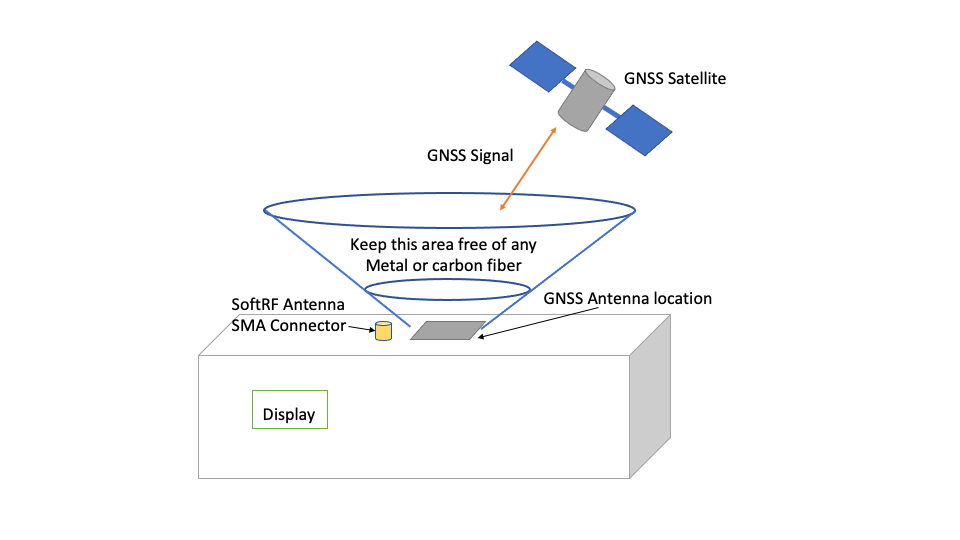
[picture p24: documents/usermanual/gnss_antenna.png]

\caption{GNSS Antenna location inside the SoftRF case}\label{fig_gnss_ant}
\end{figure}

Check for stable  GNSS reception during a test flight, ideally by using a Flarm LED, which is showing stable GNSS reception by a stady "GPS" LED in the lower left corner of the display, see Figure \ref{flarm_led}.

\begin{figure}[h]
\centering
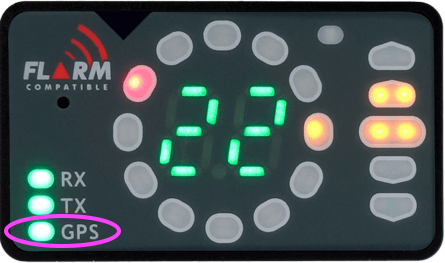
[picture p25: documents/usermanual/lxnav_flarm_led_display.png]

\caption{LXNav FLARM LED Display as an expample, notice the steady "GPS" labelled LED}\label{flarm_led}
\end{figure}

In case your GNSS reception is not stable, consider to place the SoftRF better or to modify the SoftRF to allow for an external GNSS antenna, which is totally feasible.

\FloatBarrier

\subsection{Electrical Connections}
All electrical connections are accessible through a single 9-pin D-sub connector, which is placed on the right side of the SoftRF chassis. Figure \ref{d-sub-9} shows the female connector that is part of delivery, but may be modified according to installation needs.

\begin{figure}[h]
\centering
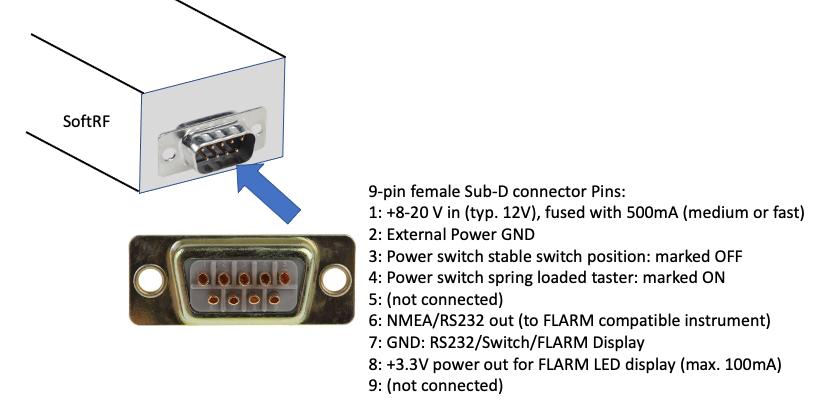
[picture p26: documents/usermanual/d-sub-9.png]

\caption{D-Sub 9 connector and pin usage}\label{d-sub-9}
\end{figure}\FloatBarrier

\subsubsection{Electrical power supply}
Electrical Power to the SoftRF is supplied to an internal power supply that operates with input voltages of 8 - 20V, supplying all internal SoftRF circuits, and the external Flarm LED display.

The Power is supplied through following of the D-Sub 9 Connector pins:

\begin{itemize}
\item Pin 1: + 8-20V = external battery "+"
\item Pin 2: Ground = external battery "-"
\end{itemize}

\begin{center}\fbox{\parbox{12cm}{The power connection shall include a blow fuse in the positive power cord, with a "M 500mA" fuse value to ensure that a shortcut failure in the SoftRF will blow the fuse.}}\end{center}

All power supply cabling behind the fuse has to be sized at least AWG30 ($0.05 {\rm mm}^2$) to ensure to blowing the fuse in case of a shortcut. It is recommended to use AWG 20 cabling for power connections in general. Cabling between the battery and the fuse has to be strong enough to blow the battery fuse, which is dependent on your the existing installation. For advice on cable sizes for certain currents, refer to FAA Advisory Circular AC 43.13-2B.

Make the fuse accessible for the pilot during flight in case the SoftRF firmware behaves unexpected, the pilot can be sure to take all power from the SoftRF.

Label the fuse in the cockpit clearly for the pilot to identify the fuse and the function, i.e. with a label called "Flarm 0.5A(M)".

To reduce the risk of interference with other equipment, all power cabling shall:
\begin{itemize}
\item be paired as close as possible together, i.e. the "+" and "-" cord shall be guided together tightly or as one double cable,
\item be distanced as far away as possible from the magnetic compass,
\item be distanced as far away as possible from the VHF radio and its cabling.
\end{itemize}

\subsubsection{NMEA out, Flarm LED}
The SoftRF D-sub 9 connector provides a RS-232 interface, that can be connected to compatible equipment.

Following NMEA sentences are implemented to be provided to external equipment:

\begin{itemize}
\item PFLAV
\item PFLAE
\item PFLAC
\item PGRMZ
\item PFLAA
\item PFLAU
\end{itemize}

These should be enough to sufficiently show: own status, closest other traffic (for alerting), most important other traffic around you.

To use this interface connect following D-Sub-9 connector pins with your equipment:
\begin{itemize}
\item Pin 6: NMEA out signal (RS-232)
\item Pin 7: signal ground
\item Pin 8: +3.3V for small (max. 100mA) devices like the Flarm LED
\end{itemize}

The author does not give any guarantee for correctness, it is the responsibility of the person integrating the equipment to ensure that voltage levels between equipment is compatible. Short-cutting the 3.3V supply might damage the SoftRF, exchanging the power line polarity might damage the Flarm LED.

The NMEA out baud rate is 38400 baud, this needs to be adjusted in the connected equipment in order to ensure proper operation.

The SoftRF does not listen to any NMEA input data, you cannot configure or update the SoftRF via NMEA, but only thogh WIFI, see section \ref{parameters}.

\subsubsection{Power Switch}
In order to conveniently integrate the SoftRF in a sailplane installation without the need to physically access the SoftRF itself, a special power switch function is integrated into the SoftRF. 

The recommended power switch is of type ON-OFF-(ON), a "Myiama Parts MS500D" or similar. It does not switch currents, the actual switching is done by the power control chip inside the SoftRF. The switch has 3 positions and is connected as follows:

\begin{itemize}
\item Stable middle position: no action; connect to D-Sub-9 Pin 7 (GND)
\item Stable OFF position: device shall be OFF; connect to D-Sub-9 Pin 3
\item unstable/spring loaded ON position: device ON command; connect to D-Sub-9 Pin 4
\end{itemize}

The function of the power switch is described in section \ref{usage_power}.

\subsection{Parameters}\label{parameters}
At least for the first 10 minutes after power-on, the SoftRF creates a WIFI network named "SoftRF-AABBCC", where AABBCC is the SoftRF Device ID of your SoftRF, find it on a label that is found on the SoftRF, and on the small display of the SoftRF.

The password for this WIFI network is 12345678, it cannot be changed.

Connect to this WIFI using your mobile phone or PC, and type following URL into your favourite web browser "http://192.168.111.1/" and hit "Enter".

This shows you a status page similar to Figure \ref{status}:

\begin{figure}[h]
\centering
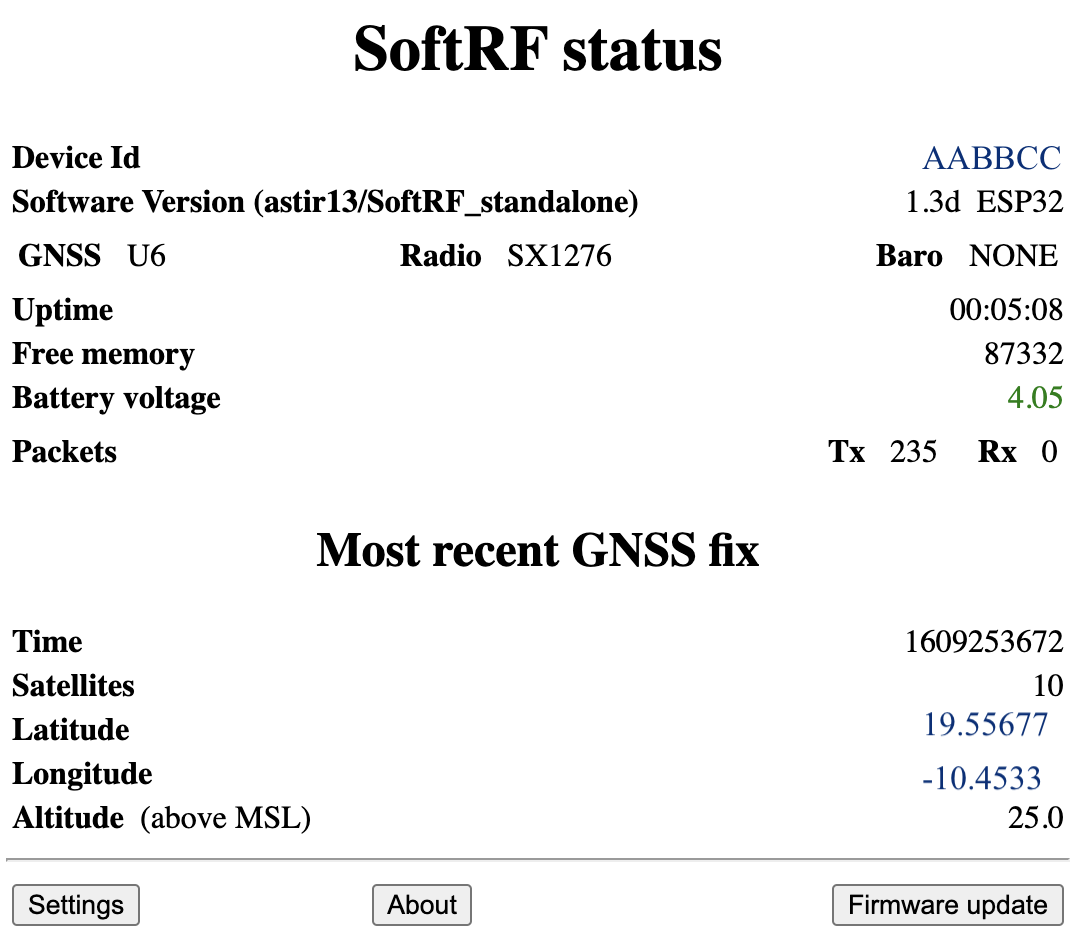
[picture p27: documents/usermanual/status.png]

\caption{Status page in web browser at http://192.168.111.1}\label{status}
\end{figure}\FloatBarrier

This example shows a status where there are 10 GNSS satellites found, and lat/long is provided. The device ID that will be found on e.g. http://glidertracker.org is shown as "AABBCC".

When pressing the "Settings" button in the lower left area of the screen, another screen is shown, see Figure \ref{settings}.

\begin{figure}[h]
\centering
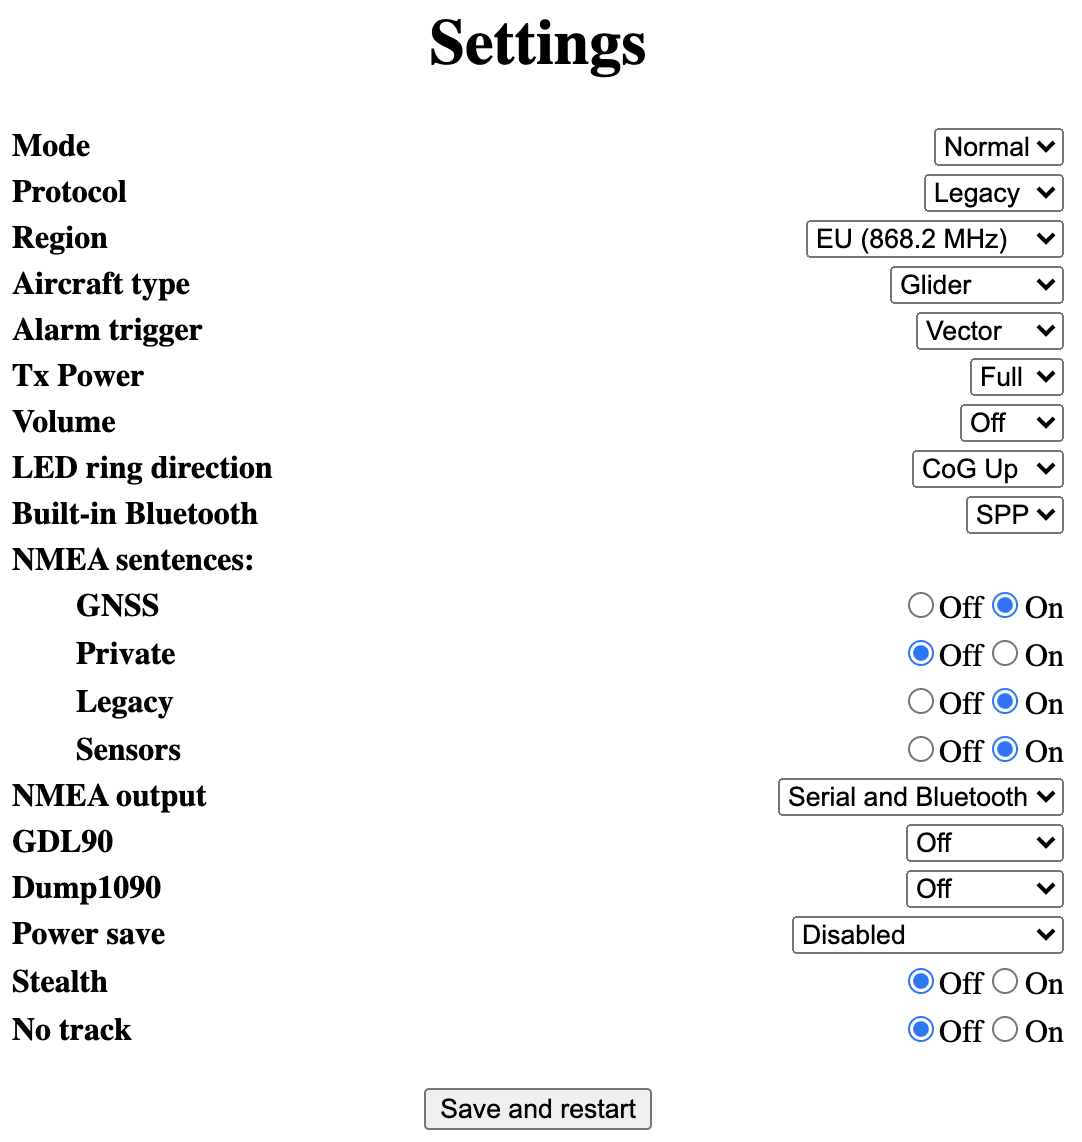
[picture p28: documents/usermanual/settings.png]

\caption{Settings page in web browser at http://192.168.111.1/settings}\label{settings}
\end{figure}\FloatBarrier

All settings can be changed. To provide proper operation for sailplane usage, however, only following settings shall be changed to stay on the safe side:

\begin{itemize}
\item Protocol: choose "legacy" if you want to see other Flarm devices and if you want to be seen by other Flarm devices; use OGN-TP, if you just want to be tracked by the open glider network database, i.e. on http://glidertracker.org. Only use other protocols than "legacy" if you really know what you do and what the consequences are.
\item Region: select the right one, to ensure you use a legal frequency. This might have to be changed when you travel with your glider to e.g. Russian Federation from European Union. However, you can not freely choose all frequencies as your SoftRF is born in a certain frequency band, which limits your choices around that band.
\item Aircraft Type: choose according to your aircraft type
\item Alarm Trigger: "Vector" is an intelligent way to create alerts from course over ground and speed to issue alerts if an impact is expected in 19 seconds or sooner; "Distance" creates alerts for the closest received traffic that is closer than 1000m horizontal and 300m vertical, with different levels of urgency, highest urgency level with distance < 400m;
\item Tx Power: Inside the EU, "EU" should always be used which limits TX power to 25mW (14 dBm) at the Antenna, which is the maximum in the EU; FULL is 17 dBm, and LOW is 2 dBm, these might be chosen at other places;
\item Built-in bluetooth: "SPP" shall be chosen if this manual shall apply
\item NMEA output: "Serial and Bluetooth" ensures you can use a Flarm LED or other cabled device and a bluetooth device to run e.g. XCSoar App at the same time. If you only want one or the other, choose accordingly, but remember that other pilots might expect bluetooth to work.
\item Power Save: "WIFI Off 10 min." allows you to disable WIFI after 10 minutes from power-up. This can be advisable to ensure no one can temper with your settings when waiting for the towplane, etc. and it safes some power.
\item Stealth: "On" informs other aircraft and ground receivers (open glider net), that you are in stealth mode, i.e. used at centralized competitions, where you do not want to share your position and climb rate with other gliders, but you want to have awareness of collision relevant traffic around you, see also http://wiki.glidernet.org/opt-in-opt-out.
\item No Track: "On" informs the open glider network to hide your position and track (OGN opt-out), including search and rescue, see also http://wiki.glidernet.org/opt-in-opt-out.
\end{itemize}

When having changed any of these settings, press the "Save and restart" button in the bottom of the page and wait approximately 20 seconds for the device to be restarted before reconnecting to the SoftRF WIFI with your PC or mobile to check if the status is ok and to {\em verify your settings} are really changed.

Always test the new settings in the concrete installation scenario before using the SoftRF equipment in flight.

\subsection{Internal Battery}\label{battery}
If not yet installed, install a "protected" LiIon 18650 battery into your SoftRF. The battery is needed to stabilize the power supply for the SoftRF itself and the optional external Flarm LED.\\

It is highly recommended for fire hazard reasons to apply a high quality 18650 Li-Ion 3.6/3.7V cell from your country that has a battery management system protection included. Buying in your country also ensures all environmental and legal battery requirements are fulfilled. One example for a very suitable type of battery is the NITECORE NL1826R 2600mAh.\\

Be aware:

\begin{itemize}
\item Never install a Li-Ion battery that is damaged, old, was overheated, is below $-15$ degrees Celsius, or is disformed in any way from its normal size.
\item Never install a Li-Ion battery that has no battery management system integrated.
\item the SoftRF has a Li-Ion battery charging controller, so there shouldn't be any danger from over- or undercharging, but safe is better than sorry, so use a battery management system battery for double protection, as should be normal in an aeroplane.
\item do not use other chemical types of batteries, as the SoftRF assumes a Li-Ion battery to be used.
\item Li-Ion batteries with battery management system typically are the ones used in devices where batteries are user-replaceable, as is the case for LED lamps and e-cigarettes.
\end{itemize}

\subsection{setup in OGN Database}
You want to be a part of the open glider net community to allow others to see your SoftRF tracking in e.g. http://glidertracker.org, then go to http://wiki.glidernet.org/ddb and register your glider there with the "Device ID" shown in the WIFI Status page, see section \ref{parameters}.

\subsection{Sticker in Cockpit}
Place the sticker shown in Figure \ref{sticker} in the cockpit for pilots to be able to find documentation about the use of the SoftRF. Simply print this page on paper, cut it out, write the Device ID, then laminate and apply in the cockpit.

\begin{figure}[h]
   \centering
	\setlength{\unitlength}{1mm}
	\thicklines
	\renewcommand{\graphwidth}{75}
	\renewcommand{\graphheight}{30}
   \begin{picture}(\graphwidth,\graphheight)
		\put(0,\the\numexpr\graphheight){\line(1,0){\graphwidth}}
		\put(0,0){\line(1,0){\graphwidth}}
		\put(0,\the\numexpr\graphheight){\line(0,-1){\graphheight}}
		\put(\graphwidth,\the\numexpr\graphheight){\line(0,-1){\graphheight}}
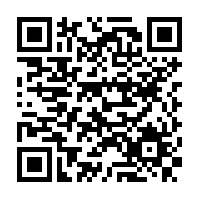
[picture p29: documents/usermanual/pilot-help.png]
		\put(1,1){}
		\put(30,25){astir13/SoftRF}
		\put(30,20){T-Beam Modem HW 1.1}
		\put(30,15){astir13/SoftRF HW 1.0}
		\put(30,8){DeviceID}
		\put(30,3){\color{cadmiumred}$\leftarrow$ scan QR for usage}
%		\put(0,\the\numexpr\graphheight - 5){\begin{tabular}{p{\the\numexpr\secondcolumnstarttable}p{6cm}}
%		\small Prepared by & \small Date/Context \\
%		\hspace{2cm}\Large Stefan Pielmeier & \hspace{2cm}\Large 2020-12-28 \\
%		\end{tabular}}
%		\put(0,\the\numexpr\graphheight - 10){\line(1,0){\graphwidth}}
%		\put(0,\the\numexpr\graphheight - 10){\line(0,1){10}}
%		\put(\secondcolumnstart,\the\numexpr\graphheight - 10){\line(0,1){10}}
  \end{picture}
  \caption{Cockpit sticker with QR code leading to online documentation}\label{sticker}
\end{figure}\FloatBarrier

\subsection{Test}\label{test}
After installation, you shall test the installed SoftRF by placing your aircraft outside, sitting inside with a closed canopy and starting all your cockpit equipment including the SoftRF. Please observe in this ground test positively that:

\begin{itemize}
\item total power consumption does not exceed the design maxima for your aircraft (measure current, consult documentation),
\item all aircraft equipment operates as usual before the installation of the SoftRF,
\item that the VHF Radio does not produce a noise that could result from interference from the SoftRF,
\item a radio check via the VHF radio is positive with good readability from a test station,
\item your magnetic compass shows the correct direction (compensation might be necessary if power supply wires pass close to the compass),
\item the SoftRF has turned on (see the display),
\item the SoftRF has GPS reception (see the status page, refer to \ref{parameters}),
\item the SoftRF transmits (see the status page transmit counter, refer to \ref{parameters}),
\item (optional) the SoftRF is registered at OGN DB with the correct Device ID (shown in the display),
\item (optional) the SoftRF is received by a nearby OGN receiver (if there is one), verify on a glider tracker web page such as http://glidertracker.org; the heading of the SoftRF might be wrong, as the GNSS cannot determine a meaningful heading without movement,
\item the SoftRF is received by another nearby SoftRF receiver (or FLARM, ideally with a display or XCSoar to verify your identification and location),
\item the SoftRF receives other SoftRF transmitters using the same protocol,
\item auto-power off after 10 minutes if you shut down the external power of the SoftRF and when the aircraft does not move.
\end{itemize}

After a successful ground test, perform a flight test or let an experienced person perform a flight test with all existing and the new equipment switched on to positively confirm that:

\begin{itemize}
\item the SoftRF can be received by other aircraft equipped with compatible equipment (ask your friends)
\item the SoftRF receives the other aircrafts: e.g. on the XCSoar moving map app
\item the SoftRF is received by the nearby OGN Receiver, to check this, log onto http://glidertracker.org, select your plane by clicking on it, and choose from the Settings "track"= 12h and "Select"=12h, this should show your whole flight, dependent also on the altitude of your flight and the location of OGN receivers;
\item after a long flight where you covered different OGN receiver areas, check out your SoftRF range as received by the OGN network using this tool: https://ktrax.kisstech.ch/flarm-liverange/.
\item keep this range analysis for later reference (yearly check).
\end{itemize}

If you are encountering unexpected results in these tests, check the installation and antenna characteristics.

Noise in the VHF radio can be removed by following steps:
\begin{itemize}
\item identifying the source of the noise: keep your radio on with squelch off, to hear the noise, switch off the other devices one by one until the noise suddenly vanishes; switch on the last device again to confirm that it is the noise generator;
\item now use a EMI Suppression Toroidal Ferrite (e.g. 3W800 from Würth), that ranges up to VHF Air Radio frequencies and wind the power supply cabling of the noise generating device 2-3 times through the ferrite (both ground and positive), as close as possible to the casing of the noisy device,
\item ensure the 2 cables ground and positive are both following each other closely until the source of power,
\item if not effective, apply the ferrite to other cables leaving the device; especially SDCard reader cables, GPS antenna cables are earlier seen to carry noise into other instruments.
\end{itemize}

\subsection{Legalities}
For the european union, the EASA CS STAN Issue 3 defines the CS-SC051c standard change for "the installation on of FLARM equipment in ELA2 type aircrafts", giving very good advice on the installation procedures to follow. This document highly recommends to follow that standard change regardless of your country, as it gives good advice.

Find the document at https://www.easa.europa.eu/sites/default/files/dfu/CS-STAN\%20Issue\%203.pdf

If you are placed in a country that implement EASA rules, you and your aircraft material personnel shall fill out a Form 123 (find it e.g. here: https://www.iaa.ie/publications/docs/default-source/publications/forms/airworthiness-application-forms/easa-form-123-issue-00) and refer to CS-SC051c.

\section{Usage}
During normal use, the SoftRF offers the following functions:

\begin{itemize}
\item transmission of own aircraft information to other aircrafts and ground receiver stations (OGN Receivers), using the chosen protocol (default is Legacy = compatible with Flarm v6)
\item reception of other aircraft information using the chosen protocol (default is Legacy = compatible with Flarm v6)
\item transmission of GNSS data, current own state, alerts and other aircraft information to connected devices through bluetooth and RS-232 cabling
\item charging of the internal battery to continue operation after the main power fails
\item display of status on a small internal display, for debug on ground
\end{itemize}

Some of these functions can be manipulated by the setup menu, refer to section \ref{parameters}.

\subsection{Power on/off and preflight check}\label{usage_power}
This section assumes, you have a Flarm LED device connected. For installations without Flarm LED, a specific procedure shall be prepared and handed to the pilots by the installation personnel.\\

\subsubsection{Switch ON}\label{power_on}
To switch the SoftRF ON, perform following steps:

\begin{itemize}
\item connect the battery to the aircraft, 
\item switch the main switch of the aircraft into "ON" position, to provide external power to the SoftRF,
\item {\bf press the SoftRF Power button into position "ON" and hold it there for 2 seconds, then release it to middle position},
\item observe the Flarm LED or a LED besides the SoftRF power switch turn on
\end{itemize}

Before flying with the SoftRF, check its function when outside on the airfield, at least 20 seconds after switching "ON":
\begin{itemize}
\item check that the SoftRF is having GNSS reception, the "GPS" LED on the Flarm LED device shall be permanently green and on, as shown in Figure \ref{flarm_led}
\item check that the SoftRF is transmitting by e.g. checking that the LED marked "TX" on the Flarm LED device is blinking green once per second, it is located just above the "GPS" LED;
\item if other aircrafts are around, and their SoftRF (or compatible devices) are switched on, check that you receive their signal, shown on a connected XCSoar device or by observing that the "RX" LED on the Flarm LED is blinking, it is located just above the "TX" LED;
\end{itemize}

\subsubsection{In-flight switch OFF}
To switch OFF your SoftRF in flight, i.e. because you get distracted by too many alerts during aero-tow or otherwise, just switch the SoftRF power switch into the "OFF" position and leave it there. The SoftRF will shut down after 5 seconds.

\subsubsection{Switch OFF after flight}
To switch off your SoftRF at the end of the flight:
\begin{itemize}
\item switch off the main power supply of the aircraft,
\item the SoftRF continues operation for some time and shuts down by itself automatically when reaching 50\% battery level (this extends the life of the battery because it is not stored fully charged)
\end{itemize} 

The auto-shutoff function only happens when the GNSS measured speed is below 10kt for at least 10 minutes while external power is off.

If you know you will use the plane again very soon, use the same procedure as for In-flight switch OFF: set the power switch to OFF, and the battery will stay full.

\subsection{Power outage}
If the aircraft's main power supply fails during flight, the SoftRF will continue to operate on power provided by the internal battery. The duration of operation depends highly on the charge in the battery, but should last at least for 60 minutes with an external Flarm LED supplied as well.

\begin{center}
\fbox{\parbox{12cm}{Do not use the SoftRF as an indicator for the state of the aircraft's main power supply, as the SoftRF will change over to internal battery power if the external supply fails. The user cannot see any difference during flight.}}
\end{center}

\subsection{Display}
The SoftRF contains a little OLED display with status information, mostly for debugging. All information shown is also available through the Status page over WIFI, see \ref{parameters}.

\begin{figure}[h]
\centering
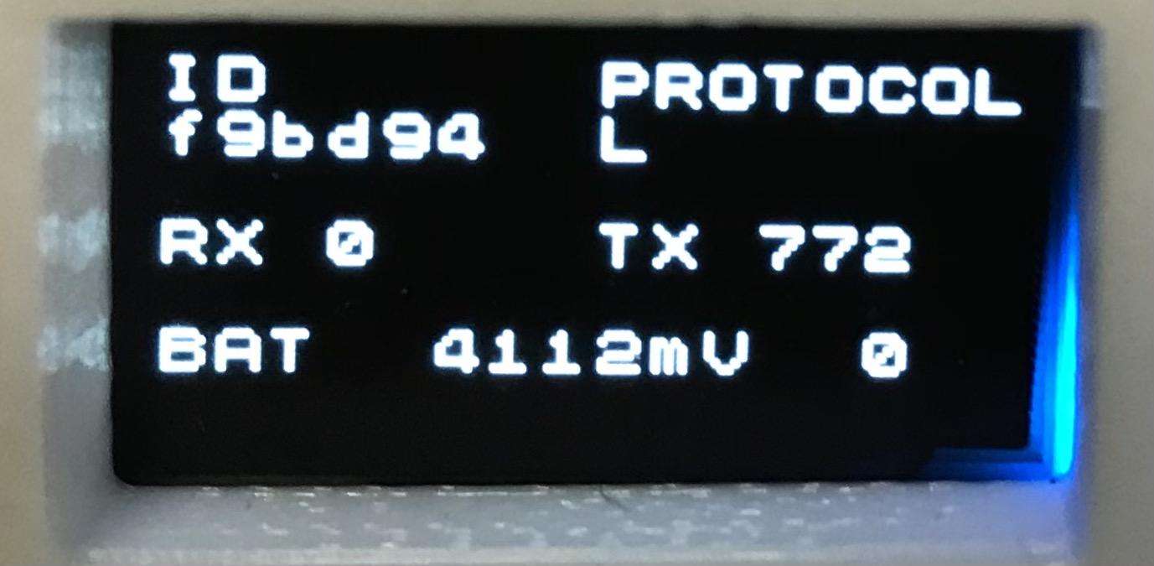
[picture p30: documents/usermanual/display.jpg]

\caption{SoftRF Display}\label{display}
\end{figure}\FloatBarrier

Figure \ref{display} shows a typical screen view of the SoftRF display with following content:

\begin{itemize}
\item top left: "ID" and below the Device ID
\item top right: "PROTOCOL" and below "L" for Legacy (= Flarm v6 compatible)
\item left middle: "RX" and to the right "0": the number of received packages from other transmitters
\item middle middle: "TX" and to the rigth "772": the number of transmitted packages, shall increase by 1 each second (roughly), when GNSS reception is working; if not incrementing, the GNSS reception might be bad (aircraft inside hangar, or GNSS antenna blocked)
\item lower left: "BAT" and to the right "4112mV" the internal battery voltage, is about 4160mV when fully charged;
\item lower right: "0" counting from "0" to "5" when in "OFF" position before the SoftRF shuts down
\end{itemize}

\subsection{Power Chip Reset}\label{power_reset}
If the operation of the power switch doesn't work as described above, you can reset the power controller chip of the SoftRF by pressing the power switch into "ON" position and hold it here for longer than 8 seconds, then release it to middle position. Then the device is OFF. After that a short press of 2 seconds into "ON" position, it should turn on. If that does not work, check the power supply of the SoftRF, the state of the internal battery, probably best done by the personnel that installed the SoftRF in that aircraft.

\subsection{Connecting XCSoar via Bluetooth}
In order to make the widespread soaring app "XCSoar" show you other traffic around your plane on the moving map and the opftional screen "Flarm Radar", please follow following steps:

\begin{itemize}
\item enter the Android Bluetooth settings menu on your mobile device running XCSoar
\item scan for other devices
\item the list of devices should show "SoftRF-ABCDEF" where ABCDEF is the Device ID of your device (visible on the little display in the SoftRF and on a sticker visible for the pilot)
\item press on the "SoftRF-ABCDEF" device to pair the SoftRF
\item open XCSoar in flying mode
\item open the XCSoar Config/Devices menu
\item identify a unused device that says "Disabled" and select it, 
\item press the "Edit" button in the bottom,
\item for the Port, select the "SoftRF-ABCDEF" device you just paired before,
\item for the Driver, select "FLARM",
\item for thee K6Bt, select "OFF",,
\item press OK
\end{itemize}

Now the SoftRF is setup and if it currently has GNSS reception, the Devices screen should show you below your SoftRF Device a line with small text saying "GPS fix; Baro; FLARM".\\

Note: Pressing the "Monitor" button in the Device menu allows you to see the NMEA traffic that is generated by the SoftRF. This might be very useful for debugging problems.

\section{Maintenance}
As the SoftRF is not mandatory equipment, there is no mandatory maintenance required.\\

However, to maintain proper operation, it is recommended at regular intervals, not longer than 12 month since the last time, the following maintenance is to be executed.

\subsection{Range check}
If your flights during the last months have been in an area with compatible OGN receivers, and you had not opted out from OGN actively, you shall check your transmission range still is as at installation time with this tool: https://ktrax.kisstech.ch/flarm-liverange/.

\subsection{Internal Battery}\label{maint_battery}
Run an internal battery test:

\begin{itemize}
\item connect the main aircraft power supply battery,
\item switch the SoftRF "ON", see \ref{power_on},
\item open the Status page as described in section \ref{parameters},
\item let the SoftRF charge the internal battery until it reads ~4.1-4.2V in the SoftRF status page, if you have enabled WIFI power saving, you might require to read the battery voltage on the SoftRF display or restart the SoftRF to provide WIFI anew,
\item disconnect external power, take the time and observe the battery voltage to decline slowly,
\item when the SoftRF shuts down 10 minutes later (auto-power off), because the aircraft is not moving and on battery power (as described in section \ref{usage_power})
\item switch the SoftRF "ON" again, and reconnect to the status page, to read the Battery voltage: if the battery voltage is below 4.00 (Volt), the battery might need a capacity check and possibly replacement, see \ref{battery}.
\item if the battery voltage after the 10 minutes test is greater or equal 4.00 (Volt), the battery can be expected to keep up operations for at least 60 minutes when in flight
\end{itemize}

\subsection{Firmware}

\begin{itemize}
\item connect to the status page as described in section \ref{maint_battery}
\item check https://github.com/astir13/SoftRF/wiki/Updates if there is a new Software Version for your device,
\item in case there is a new firmware for your device and you decide the updates are relevant for your use, continue this list:
\item continue on a PC (Mac, Linux, Windows are ok): download the new firmware for your device from https://github.com/astir13/SoftRF/wiki/Updates (you need internet connection for that), be careful to check that the two HW Revisions match the ones on the sticker of your SoftRF (T-Beam and astir13/SoftRF HW revision)
\item disconnect from the internet WIFI,
\item connect to the SoftRF WIFI,
\item open the status page of the SoftRF,
\item click on the button "Firmware Update",
\item observe a new page opens called "Firmware update",
\item click on "Choose File" button,
\item select the downloaded file name from your Download directory, it shall end with ".bin", if you downloaded a zip file, you might need to unzip it first to get to the ".bin" file,
\item observe the filename be shown besides the "Choose File" button,
\item click on the "Update" button, to start the upload,
\item {\bf do not shut down power now!}
\item observe the update counter to count to 100, then wait for at least 3 minutes without taking power off the SoftRF,
\item in case the counter stops for more than 60 seconds without update before reaching 100: wait 60 seconds more, then perform a power chip reset (see section \ref{power_reset} and retry;
\item after above procedure, the SoftRF should restart and display the new firmware revision in the status page and on the built-in display
\item run a functional test, see section \ref{test}.

\end{itemize}

\section{Technical Data}

\subsection{Hard- and Software}
The SoftRF is open source hardware and software. Please find the SoftRF firmware and hardware descriptions at http://github.com/astir13/SoftRF.

\subsection{Transmit Spectral Purity and Power}
For T-Beam HW revision 1.1, following transmit spectrum was recorded in EU power setting, which shows very good spectral cleanness and power below the maximum allowed +14dBm:

\begin{figure}[h]
\centering
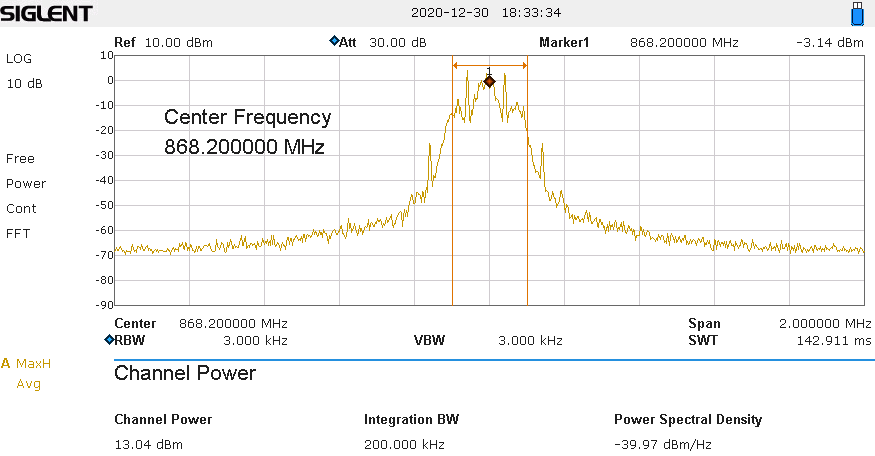
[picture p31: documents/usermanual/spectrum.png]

\caption{Transmit Spectrum of the T-Bone rev.\/1.1 Modem, used in astir13/SoftRF HW rev.\/1.0}\label{spectrum}
\end{figure}\FloatBarrier

\subsection{General Data}
Applicable for use with the "Legacy" protocol (compatible with Flarm v6):

\begin{tabular}{r|c|p{6cm}}\hline
Item & Value & Unit\\\hline\hline
Supply Voltage & 8-20 & V\\\hline
typical supply current & 100 & mA\\\hline
maximum supply current & 300 & mA  \\\hline
weight & 250 & g (including battery, antenna, power switch, cabling and Flarm LED)\\\hline
ambient temperature range & 0 - 40 & $^\circ$C \\\hline
battery type & 18650 Li-Ion & with protection\\
battery voltage typ. & 3.7 & V\\
max. & 4.2 & V\\
min. protection shut off & 3.1 & V\\\hline
channel bandwidth & 125 & kHz\\
modulation type & 2-FSK & \\
bitrate & 100 & kbps\\
max. transmit power & +14 & dBm in "EU" setting\\
 & +17 & dBm in "FULL" setting\\
 & +3 & dBm in "LOW" setting\\
max. transmit duty cycle & $< 1$ & \%\\
transmit frequency stability & +/-15 & kHz\\\hline
GNSS chipset & uBlox NEO6M & \\\hline

\end{tabular}

\section{License}
Copyright (C)  2020-2021 Stefan Pielmeier (sp@symlinux.com)\\

\begin{center}
\fbox{\parbox{12cm}{Permission is granted to copy, distribute and/or modify this document
    under the terms of the GNU Free Documentation License, Version 1.3
    or any later version published by the Free Software Foundation;
    with no Invariant Sections, no Front-Cover Texts, and no Back-Cover Texts.
    A copy of the license is included in the section entitled "GNU
    Free Documentation License".}}
\end{center}    
\end{document}

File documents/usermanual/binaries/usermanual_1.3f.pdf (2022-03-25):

# User Manual

## SoftRF (Github astir13/SoftRF fork)

## matching SoftRF firmware version 1.3f

2022-03-25

Thanks to all contributrs of the Github SoftRF Project.


1

astir13/SoftRF | User Manual v.1.3f rev.0 | pg. 2(19)

## 1 Revision History

## Revision History

Revision | Date | Author(s) | Description
1.3e rev. 0 | 2020-12-30 | astir13 | created from scratch
1.3e rev. 1 | 2020-12-31 | astir13 | editorials, added Display section, added Revi-
| | | sion History, corrected links to fork
1.3f rev. 0 | 2022-03-25 | astir13 | autopower off at 50% battery level, not after
| | | 10 minutes

## 2 Acronyms

Baidu The GNSS deployed by China

FANET another open anti-collision protocol

FLARM The protocol used by the equipment traded by the company Flarm; the term legacy is used in the SoftRF setup and display ”L”, to indicate that the SoftRF does not use the Flarm protocol, as it is private and may not be used; however, the SoftRF uses a protocol, that is understood by Flarm devices and can receive Flarm transmissions as of now.

GLONASS The GNSS deployed by the Russian Federation

GNSS Global Navigation Satellite System; this can be GPS but also Glonass, Baidu or Gallileo, dependent on the chipset on the SoftRF; current SoftRF use GLONASS and GPS

GPS Global Positioning System: the GNSS deployed by the USA

Gallileo The GNSS deployed by the European Union and ESA

OGN The open glider net, see http://wiki.glidernet.org/

OGNTP another open air traffic awareness protocol

RS-232 the cable-based data line protocol used for the communication between SoftRF and other cockpit equipment like Flarm LED, LX Nav/LXNavigation flight computers and smart e-varios like EOS/ERA/S-80 or S-100.

## 3 Disclaimer

THIS DOCUMENT IS PROVIDED ”AS IS”, WITHOUT WARRANTY OF ANY KIND, EXPRESS OR IMPLIED, INCLUDING BUT NOT LIMITED TO THE WARRANTIES OF MERCHANTABILITY, FITNESS FOR A PARTICULAR PURPOSE AND NONIN-FRINGEMENT. IN NO EVENT SHALL THE AUTHORS OR COPYRIGHT HOLDERS BE LIABLE FOR ANY CLAIM, DAMAGES OR OTHER LIABILITY, WHETHER IN AN ACTION OF CONTRACT, TORT OR OTHERWISE, ARISING FROM, OUT OF OR IN CONNECTION WITH THE SOFTWARE OR THE USE OR OTHER DEALINGS IN THE SOFTWARE, DOCUMENTATION OR HARDWARE DESCRIBED HERE.

astir13/SoftRF | User Manual v.1.3f rev.0 | pg. 3(19)

## 4 Foreword

The SoftRF based air traffic awareness devices use the ISM bands. The devices are good tools to aid pilot situational awareness by often giving successful information about the position, direction, vertical and horizontal speed of other aviation traffic. However, they are not to be trusted all times and in all situations. Do not trust your life to this information, and only trust your eyes for VFR flight anti-collision avoidance.
SoftRF, Flarm, FANET, OGN-Tracker, Pilot-Aware, Skytraxx use transmission and reception via the so-called ISM bands, which are used for many industrial, scientific and medical purposes. Thus, the used frequencies are not exclusively reserved for air traffic transmissions, and can be used for multiple other purposes, also on board of aircrafts. No frequency coordination/licensing is provided by the authorities in most countries, which is very convenient, but there also is no protection against interference from other equipment.

As a consequence of potential interference from other equipment using the same frequency bands, reception in your own installation or the installation in other planes can be impaired, leading to potential ”ghost” traffic, or (worse) masking existing traffic away, i.e. ”hiding” other traffic.

Therefore, you should never trust such installations, nor the fact that you can detect all other planes in your vicinity using these tools. Additionally, commercial planes and motorplanes rarely use these protocols, and there is no legal carrige requirement for such equipment.
The above statements are not true for certified Mode-S transponders and TCAS equipment. Air transponders operate on reserved frequencies, may only be operated when certified and properly tested, with about 1000 times higher transmit power, and are proved to work efficiently and effectively for sailplanes, small aeroplanes and commercial planes of all sizes. In the eyes of the author, certified transponder based communication is the future of air anti-collision for all segments, but in some countries you may not be allowed such equipment in small areoplanes, drones, ultralights, and so on. So the ISM band based air traffic awareness equipment might have a long future ahead.
A note on the protocol: While Flarm is the most used protocol, it is advised to consider using the other protocols like OGN-TP because they are open source. Flarm will, thanks to the Open Glider Net initiative, not change protocol anymore, because most pilots highly rely on the existence of the open glider network to track their planes safely throughout each journey. If Flarm would change the protocol one day, remember that you can change your SoftRF to use e.g. OGN-TP through the settings menu very easily, and all open glider Net trackers would be able to ”see” your plane in real time again.

## 5 Basics about SoftRF

The SoftRF main purpose is to transmit anti-collision data to other devices. In order to do so, it finds information about the own aircraft and packages it into a protocol, which then is transmitted through the SoftRF antenna on UHF ISM band frequencies.
Following data is transmitted (example from legacy protocol (Flarm v6):
- your position (latitude and longitude),
- the GPS status,
- horizontal speed (speed over ground),
- heading (over ground from GNSS),
- vertical speed (climb or sink rate),

astir13/SoftRF | User Manual v.1.3f rev.0 | pg. 4(19)
- your identification,
- the type of aircraft,
- stealth mode (for competitions),
- do not track information (opt-out from OGN).

The other purpose is to receive such transmissions from other aircrafts around you and to provide this information to your other cockpit devices to issue alerts and situational awareness. Other devices can be:

- Android tablet or phone with XCSoar App installed
- Flarm LED
- LXNavigation ERA/EOS 80 devices
- LXNav S80/100 devices
- larger Flight computer series from LXNavigation and LXNav, or self-built

From the point in time when the SoftRF has successful reception from GNSS, it is transmitting status and all received information over following interfaces if configured correctly:

- Bluetooth (used for mobile phone/tablet Apps like XCSoar)
- NMEA cable based output (RS-232) at a speed of 38400 baud

## 6 Installation

The SoftRF has to be built into a stable case, secured against overheating, examples can be seen at https://github.com/lyusupov/SoftRF/tree/master/case.
For running the astir13 fork of the SoftRF firmware, some hardware additions are required that are described in the Wiki found at https://github.com/astir13/SoftRF/wiki.

### 6.1 Mechanical

Fasten the SoftRF case and all wirings tightly with other equipment behind the instrument cluster, i.e. using wire straps. As a rule of thumb, an installation shall be able to handle +/-10G, so if your SoftRF weights 200g, the installation shall sustain a 20N force, applied at the SoftRF in each direction.
The optional FlarmLED display shall be mounted securely into the instrument panel using screws, because the supplied adhesive tape is not sufficient, follow the instructions of the producer.

No mechanical installations may limit or change existing mechanical functions of the aircraft.

### 6.2 SoftRF Antenna

The golden SMA female connector of the SoftRF has to be connected to a matching SMA male connector leading the RF signal to the SoftRF antenna resonating in the band of your SoftRF’s transmissions. If your SoftRF is deployed in the European Union, the frequency is 868.2MHz, and the antenna shall be resonant on this frequency. You can mount the antenna directly onto the SoftRF case or connect the antenna through a 50Ω RF cable such as RG174 for lenghts < 1m. For cable lengths above 1m, good results can be achived using e.g. BELDEN RF 200 cable which at many places can be bought already fully configured with SMA connectors attached.
A well-proven design is a so-called ground plane antenna on top of the instrument cluster cover, like shown in Figure 1.

astir13/SoftRF | User Manual v.1.3f rev.0 | pg. 5(19)

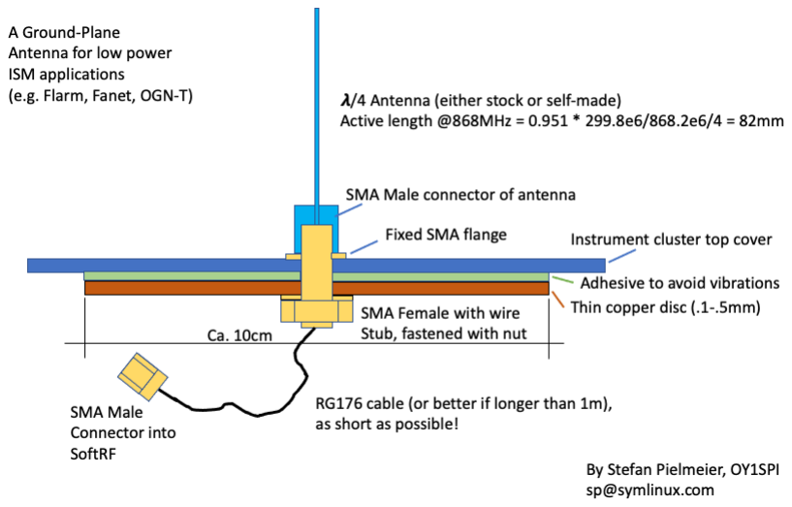
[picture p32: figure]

Figure 1: Example ground plane antenna construction that can be used for the SoftRF

Beware that there are many antennas out there that say they are Flarm compatible, but they might actually not be resonant at the required frequency. Before use, it might be relevant to test your antenna with an antenna tester to be sure it is resonant at the right frequencies. Suitable Antenna testers (e.g. Nano VNA from aliexpress) are owned by radio nerds like Amateur Radio girls and guys, find one to help you if you don’t know anything about antennas, because this is an important part of achieving a good transmission range.

### 6.3 GNSS Antenna

The SoftRF needs a valid 3D position from a global navigation satellite system (GNSS), e.g. GPS or GLONASS, to define timing and the own aircraft’s

- position,
- altitude,
- horizontal speed (speed over ground),
- vertical speed (climb or decend), and
- heading.

The GNSS antenna is integrated into the SoftRF case’s top, just in the middle, see Figure 2. Therefore, the case shall be mounted with the SoftRF display to the side and the SoftRF golden antenna plug to the top, as close as possible to the instrument cluster top cover as possible. No metal parts shall obstruct the GNSS reception field above the SoftRF middle section, otherwise GNSS reception might be impaired.
Check for stable GNSS reception during a test flight, ideally by using a Flarm LED, which is showing stable GNSS reception by a stady ”GPS” LED in the lower left corner of the display, see Figure 3.
In case your GNSS reception is not stable, consider to place the SoftRF better or to modify the SoftRF to allow for an external GNSS antenna, which is totally feasible.

astir13/SoftRF | User Manual v.1.3f rev.0 | pg. 6(19)

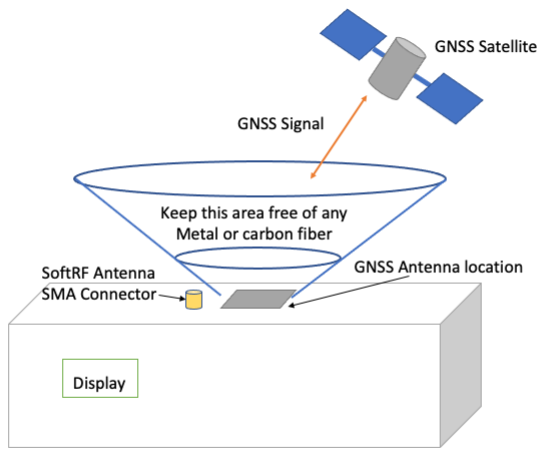
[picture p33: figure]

Figure 2: GNSS Antenna location inside the SoftRF case

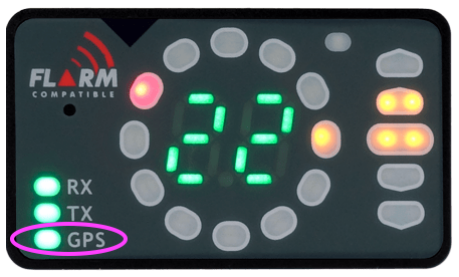
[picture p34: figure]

Figure 3: LXNav FLARM LED Display as an expample, notice the steady ”GPS” labelled LED

### 6.4 Electrical Connections

All electrical connections are accessible through a single 9-pin D-sub connector, which is placed on the right side of the SoftRF chassis. Figure 4 shows the female connector that is part of delivery, but may be modified according to installation needs.

astir13/SoftRF | User Manual v.1.3f rev.0 | pg. 7(19)

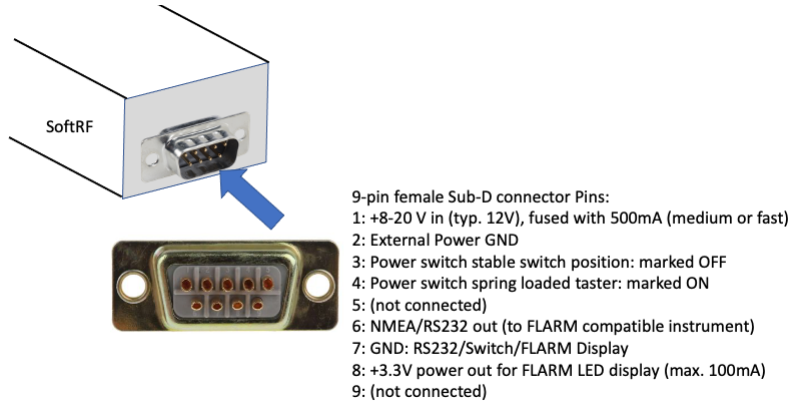
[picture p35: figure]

Figure 4: D-Sub 9 connector and pin usage

### 6.4.1 Electrical power supply

Electrical Power to the SoftRF is supplied to an internal power supply that operates with input voltages of 8 - 20V, supplying all internal SoftRF circuits, and the external Flarm LED display.
The Power is supplied through following of the D-Sub 9 Connector pins:
- Pin 1: + 8-20V = external battery ”+”
- Pin 2: Ground = external battery ”-”

The power connection shall include a blow fuse in the positive power cord, with a ”M 500mA” fuse value to ensure that a shortcut failure in
the SoftRF will blow the fuse.

All power supply cabling behind the fuse has to be sized at least AWG30 (0.05mm²
) to
ensure to blowing the fuse in case of a shortcut. It is recommended to use AWG 20 cabling for power connections in general. Cabling between the battery and the fuse has to be strong enough to blow the battery fuse, which is dependent on your the existing installation. For advice on cable sizes for certain currents, refer to FAA Advisory Circular AC 43.13-2B. Make the fuse accessible for the pilot during flight in case the SoftRF firmware behaves unexpected, the pilot can be sure to take all power from the SoftRF.
Label the fuse in the cockpit clearly for the pilot to identify the fuse and the function, i.e. with a label called ”Flarm 0.5A(M)”.
To reduce the risk of interference with other equipment, all power cabling shall:
- be paired as close as possible together, i.e. the ”+” and ”-” cord shall be guided together tightly or as one double cable,
- be distanced as far away as possible from the magnetic compass,
- be distanced as far away as possible from the VHF radio and its cabling.

### 6.4.2 NMEA out, Flarm LED

The SoftRF D-sub 9 connector provides a RS-232 interface, that can be connected to compatible equipment.
Following NMEA sentences are implemented to be provided to external equipment:

astir13/SoftRF | User Manual v.1.3f rev.0 | pg. 8(19)
- PFLAV
- PFLAE
- PFLAC
- PGRMZ
- PFLAA
- PFLAU

These should be enough to sufficiently show: own status, closest other traffic (for alerting), most important other traffic around you.
To use this interface connect following D-Sub-9 connector pins with your equipment:
- Pin 6: NMEA out signal (RS-232)
- Pin 7: signal ground
- Pin 8: +3.3V for small (max. 100mA) devices like the Flarm LED

The author does not give any guarantee for correctness, it is the responsibility of the person integrating the equipment to ensure that voltage levels between equipment is compatible. Short-cutting the 3.3V supply might damage the SoftRF, exchanging the power line polarity might damage the Flarm LED.
The NMEA out baud rate is 38400 baud, this needs to be adjusted in the connected equipment in order to ensure proper operation.
The SoftRF does not listen to any NMEA input data, you cannot configure or update the SoftRF via NMEA, but only thogh WIFI, see section 6.5.

### 6.4.3 Power Switch

In order to conveniently integrate the SoftRF in a sailplane installation without the need to physically access the SoftRF itself, a special power switch function is integrated into the SoftRF.
The recommended power switch is of type ON-OFF-(ON), a ”Myiama Parts MS500D” or similar. It does not switch currents, the actual switching is done by the power control chip inside the SoftRF. The switch has 3 positions and is connected as follows:
- Stable middle position: no action; connect to D-Sub-9 Pin 7 (GND)
- Stable OFF position: device shall be OFF; connect to D-Sub-9 Pin 3
- unstable/spring loaded ON position: device ON command; connect to D-Sub-9 Pin 4

The function of the power switch is described in section 7.1.

### 6.5 Parameters

At least for the first 10 minutes after power-on, the SoftRF creates a WIFI network named ”SoftRF-AABBCC”, where AABBCC is the SoftRF Device ID of your SoftRF, find it on a label that is found on the SoftRF, and on the small display of the SoftRF.
The password for this WIFI network is 12345678, it cannot be changed.
Connect to this WIFI using your mobile phone or PC, and type following URL into your favourite web browser ”http://192.168.111.1/” and hit ”Enter”.
This shows you a status page similar to Figure 5:

astir13/SoftRF | User Manual v.1.3f rev.0 | pg. 9(19)


Figure 5: Status page in web browser at http://192.168.111.1

This example shows a status where there are 10 GNSS satellites found, and lat/long is provided. The device ID that will be found on e.g. http://glidertracker.org is shown as ”AABBCC”.
When pressing the ”Settings” button in the lower left area of the screen, another screen is shown, see Figure 6.

astir13/SoftRF | User Manual v.1.3f rev.0 | pg. 10(19)


Figure 6: Settings page in web browser at http://192.168.111.1/settings

All settings can be changed. To provide proper operation for sailplane usage, however, only following settings shall be changed to stay on the safe side:

- Protocol: choose ”legacy” if you want to see other Flarm devices and if you want to be seen by other Flarm devices; use OGN-TP, if you just want to be tracked by the open glider network database, i.e. on http://glidertracker.org. Only use other protocols than ”legacy” if you really know what you do and what the consequences are.
- Region: select the right one, to ensure you use a legal frequency. This might have to be changed when you travel with your glider to e.g. Russian Federation from European Union. However, you can not freely choose all frequencies as your SoftRF is born in a certain frequency band, which limits your choices around that band.
- Aircraft Type: choose according to your aircraft type
- Alarm Trigger: ”Vector” is an intelligent way to create alerts from course over ground and speed to issue alerts if an impact is expected in 19 seconds or sooner; ”Distance” creates alerts for the closest received traffic that is closer than 1000m horizontal and 300m vertical, with different levels of urgency, highest urgency level with distance ¡ 400m;
- Tx Power: Inside the EU, ”EU” should always be used which limits TX power to 25mW (14 dBm) at the Antenna, which is the maximum in the EU; FULL is 17 dBm, and LOW is 2 dBm, these might be chosen at other places;
- Built-in bluetooth: ”SPP” shall be chosen if this manual shall apply

astir13/SoftRF | User Manual v.1.3f rev.0 | pg. 11(19)
- NMEA output: ”Serial and Bluetooth” ensures you can use a Flarm LED or other
cabled device and a bluetooth device to run e.g. XCSoar App at the same time. If you only want one or the other, choose accordingly, but remember that other pilots might expect bluetooth to work.
- Power Save: ”WIFI Off 10 min.” allows you to disable WIFI after 10 minutes from power-up. This can be advisable to ensure no one can temper with your settings when waiting for the towplane, etc. and it safes some power.
- Stealth: ”On” informs other aircraft and ground receivers (open glider net), that you are in stealth mode, i.e. used at centralized competitions, where you do not want to share your position and climb rate with other gliders, but you want to have awareness of collision relevant traffic around you, see also http://wiki.glidernet.org/opt-in-opt-out.
- No Track: ”On” informs the open glider network to hide your position and track (OGN opt-out), including search and rescue, see also http://wiki.glidernet.org/optin-opt-out.

When having changed any of these settings, press the ”Save and restart” button in the bottom of the page and wait approximately 20 seconds for the device to be restarted before reconnecting to the SoftRF WIFI with your PC or mobile to check if the status is ok and to verify your settings are really changed.
Always test the new settings in the concrete installation scenario before using the SoftRF equipment in flight.

### 6.6 Internal Battery

If not yet installed, install a ”protected” LiIon 18650 battery into your SoftRF. The battery is needed to stabilize the power supply for the SoftRF itself and the optional external Flarm LED.

It is highly recommended for fire hazard reasons to apply a high quality 18650 Li-Ion 3.6/3.7V cell from your country that has a battery management system protection included. Buying in your country also ensures all environmental and legal battery requirements are fulfilled. One example for a very suitable type of battery is the NITECORE NL1826R 2600mAh.

Be aware:

- Never install a Li-Ion battery that is damaged, old, was overheated, is below −15 degrees Celsius, or is disformed in any way from its normal size.
- Never install a Li-Ion battery that has no battery management system integrated.
- the SoftRF has a Li-Ion battery charging controller, so there shouldn’t be any danger from over- or undercharging, but safe is better than sorry, so use a battery management system battery for double protection, as should be normal in an aeroplane.
- do not use other chemical types of batteries, as the SoftRF assumes a Li-Ion battery to be used.
- Li-Ion batteries with battery management system typically are the ones used in devices where batteries are user-replaceable, as is the case for LED lamps and ecigarettes.

astir13/SoftRF | User Manual v.1.3f rev.0 | pg. 12(19)

### 6.7 setup in OGN Database

You want to be a part of the open glider net community to allow others to see your SoftRF tracking in e.g. http://glidertracker.org, then go to http://wiki.glidernet.org/ddb and register your glider there with the ”Device ID” shown in the WIFI Status page, see section 6.5.

### 6.8 Sticker in Cockpit

Place the sticker shown in Figure 7 in the cockpit for pilots to be able to find documentation about the use of the SoftRF. Simply print this page on paper, cut it out, write the Device ID, then laminate and apply in the cockpit.

astir13/SoftRF
T-Beam Modem HW 1.1
astir13/SoftRF HW 1.0

DeviceID
← scan QR for usage

Figure 7: Cockpit sticker with QR code leading to online documentation

### 6.9 Test

After installation, you shall test the installed SoftRF by placing your aircraft outside, sitting inside with a closed canopy and starting all your cockpit equipment including the SoftRF. Please observe in this ground test positively that:

- total power consumption does not exceed the design maxima for your aircraft (measure current, consult documentation),
- all aircraft equipment operates as usual before the installation of the SoftRF,
- that the VHF Radio does not produce a noise that could result from interference from the SoftRF,
- a radio check via the VHF radio is positive with good readability from a test station,
- your magnetic compass shows the correct direction (compensation might be necessary if power supply wires pass close to the compass),
- the SoftRF has turned on (see the display),
- the SoftRF has GPS reception (see the status page, refer to 6.5),
- the SoftRF transmits (see the status page transmit counter, refer to 6.5),
- (optional) the SoftRF is registered at OGN DB with the correct Device ID (shown in the display),
- (optional) the SoftRF is received by a nearby OGN receiver (if there is one), verify on a glider tracker web page such as http://glidertracker.org; the heading of the SoftRF might be wrong, as the GNSS cannot determine a meaningful heading without movement,
- the SoftRF is received by another nearby SoftRF receiver (or FLARM, ideally with a display or XCSoar to verify your identification and location),

astir13/SoftRF | User Manual v.1.3f rev.0 | pg. 13(19)
- the SoftRF receives other SoftRF transmitters using the same protocol,
- auto-power off after 10 minutes if you shut down the external power of the SoftRF and when the aircraft does not move.

After a successful ground test, perform a flight test or let an experienced person perform a flight test with all existing and the new equipment switched on to positively confirm that:

- the SoftRF can be received by other aircraft equipped with compatible equipment (ask your friends)
- the SoftRF receives the other aircrafts: e.g. on the XCSoar moving map app
- the SoftRF is received by the nearby OGN Receiver, to check this, log onto http://glidertracker.org, select your plane by clicking on it, and choose from the Settings ”track”= 12h and ”Select”=12h, this should show your whole flight, dependent also on the altitude of
your flight and the location of OGN receivers;
- after a long flight where you covered different OGN receiver areas, check out your SoftRF range as received by the OGN network using this tool: https://ktrax.kisstech.ch/flarm-liverange/.
- keep this range analysis for later reference (yearly check).

If you are encountering unexpected results in these tests, check the installation and antenna characteristics.
Noise in the VHF radio can be removed by following steps:
- identifying the source of the noise: keep your radio on with squelch off, to hear the noise, switch off the other devices one by one until the noise suddenly vanishes; switch on the last device again to confirm that it is the noise generator;
- now use a EMI Suppression Toroidal Ferrite (e.g. 3W800 from W¨urth), that ranges up to VHF Air Radio frequencies and wind the power supply cabling of the noise generating device 2-3 times through the ferrite (both ground and positive), as close as possible to the casing of the noisy device,
- ensure the 2 cables ground and positive are both following each other closely until the source of power,
- if not effective, apply the ferrite to other cables leaving the device; especially SD-Card reader cables, GPS antenna cables are earlier seen to carry noise into other instruments.

### 6.10 Legalities

For the european union, the EASA CS STAN Issue 3 defines the CS-SC051c standard change for ”the installation on of FLARM equipment in ELA2 type aircrafts”, giving very
good advice on the installation procedures to follow. This document highly recommends
to follow that standard change regardless of your country, as it gives good advice.
Find the document at https://www.easa.europa.eu/sites/default/files/dfu/CS-STAN%20Issue%203.pdf If you are placed in a country that implement EASA rules, you and your aircraft material
personnel shall fill out a Form 123 (find it e.g. here: https://www.iaa.ie/publications/docs/defaultsource/publications/forms/airworthiness-application-forms/easa-form-123-issue-00) and refer to CS-SC051c.

astir13/SoftRF | User Manual v.1.3f rev.0 | pg. 14(19)

## 7 Usage

During normal use, the SoftRF offers the following functions:

- transmission of own aircraft information to other aircrafts and ground receiver stations (OGN Receivers), using the chosen protocol (default is Legacy = compatible with Flarm v6)
- reception of other aircraft information using the chosen protocol (default is Legacy = compatible with Flarm v6)
- transmission of GNSS data, current own state, alerts and other aircraft information to connected devices through bluetooth and RS-232 cabling
- charging of the internal battery to continue operation after the main power fails
- display of status on a small internal display, for debug on ground

Some of these functions can be manipulated by the setup menu, refer to section 6.5.

### 7.1 Power on/off and preflight check

This section assumes, you have a Flarm LED device connected. For installations without Flarm LED, a specific procedure shall be prepared and handed to the pilots by the installation personnel.

### 7.1.1 Switch ON

To switch the SoftRF ON, perform following steps:

- connect the battery to the aircraft,
- switch the main switch of the aircraft into ”ON” position, to provide external power to the SoftRF,
- press the SoftRF Power button into position ”ON” and hold it there for 2 seconds, then release it to middle position,
- observe the Flarm LED or a LED besides the SoftRF power switch turn on

Before flying with the SoftRF, check its function when outside on the airfield, at least 20 seconds after switching ”ON”:

- check that the SoftRF is having GNSS reception, the ”GPS” LED on the Flarm LED device shall be permanently green and on, as shown in Figure 3
- check that the SoftRF is transmitting by e.g. checking that the LED marked ”TX” on the Flarm LED device is blinking green once per second, it is located just above the ”GPS” LED;
- if other aircrafts are around, and their SoftRF (or compatible devices) are switched on, check that you receive their signal, shown on a connected XCSoar device or by observing that the ”RX” LED on the Flarm LED is blinking, it is located just above the ”TX” LED;

### 7.1.2 In-flight switch OFF

To switch OFF your SoftRF in flight, i.e. because you get distracted by too many alerts during aero-tow or otherwise, just switch the SoftRF power switch into the ”OFF” position and leave it there. The SoftRF will shut down after 5 seconds.

astir13/SoftRF | User Manual v.1.3f rev.0 | pg. 15(19)

### 7.1.3 Switch OFF after flight

To switch off your SoftRF at the end of the flight:

- switch off the main power supply of the aircraft,
- the SoftRF continues operation for some time and shuts down by itself automatically when reaching 50% battery level (this extends the life of the battery because it is not stored fully charged)

The auto-shutoff function only happens when the GNSS measured speed is below 10kt for at least 10 minutes while external power is off.
If you know you will use the plane again very soon, use the same procedure as for In-flight switch OFF: set the power switch to OFF, and the battery will stay full.

### 7.2 Power outage

If the aircraft’s main power supply fails during flight, the SoftRF will continue to operate on power provided by the internal battery. The duration of operation depends highly on the charge in the battery, but should last at least for 60 minutes with an external Flarm LED supplied as well.

Do not use the SoftRF as an indicator for the state of the aircraft’s main power supply, as the SoftRF will change over to internal battery power if the external supply fails. The user cannot see any difference during flight.

### 7.3 Display

The SoftRF contains a little OLED display with status information, mostly for debugging. All information shown is also available through the Status page over WIFI, see 6.5.


Figure 8: SoftRF Display

Figure 8 shows a typical screen view of the SoftRF display with following content:

- top left: ”ID” and below the Device ID
- top right: ”PROTOCOL” and below ”L” for Legacy (= Flarm v6 compatible)
- left middle: ”RX” and to the right ”0”: the number of received packages from other transmitters
- middle middle: ”TX” and to the rigth ”772”: the number of transmitted packages, shall increase by 1 each second (roughly), when GNSS reception is working; if not incrementing, the GNSS reception might be bad (aircraft inside hangar, or GNSS antenna blocked)
- lower left: ”BAT” and to the right ”4112mV” the internal battery voltage, is about 4160mV when fully charged;
- lower right: ”0” counting from ”0” to ”5” when in ”OFF” position before the SoftRF shuts down

astir13/SoftRF | User Manual v.1.3f rev.0 | pg. 16(19)

### 7.4 Power Chip Reset

If the operation of the power switch doesn’t work as described above, you can reset the power controller chip of the SoftRF by pressing the power switch into ”ON” position and hold it here for longer than 8 seconds, then release it to middle position. Then the device is OFF. After that a short press of 2 seconds into ”ON” position, it should turn on. If that does not work, check the power supply of the SoftRF, the state of the internal battery, probably best done by the personnel that installed the SoftRF in that aircraft.

### 7.5 Connecting XCSoar via Bluetooth

In order to make the widespread soaring app ”XCSoar” show you other traffic around your plane on the moving map and the opftional screen ”Flarm Radar”, please follow following steps:

- enter the Android Bluetooth settings menu on your mobile device running XCSoar
- scan for other devices
- the list of devices should show ”SoftRF-ABCDEF” where ABCDEF is the Device ID of your device (visible on the little display in the SoftRF and on a sticker visible for the pilot)
- press on the ”SoftRF-ABCDEF” device to pair the SoftRF
- open XCSoar in flying mode
- open the XCSoar Config/Devices menu
- identify a unused device that says ”Disabled” and select it,
- press the ”Edit” button in the bottom,
- for the Port, select the ”SoftRF-ABCDEF” device you just paired before,
- for the Driver, select ”FLARM”,
- for thee K6Bt, select ”OFF”,,
- press OK

Now the SoftRF is setup and if it currently has GNSS reception, the Devices screen should show you below your SoftRF Device a line with small text saying ”GPS fix; Baro; FLARM”.

Note: Pressing the ”Monitor” button in the Device menu allows you to see the NMEA traffic that is generated by the SoftRF. This might be very useful for debugging problems.

## 8 Maintenance

As the SoftRF is not mandatory equipment, there is no mandatory maintenance required.

However, to maintain proper operation, it is recommended at regular intervals, not longer than 12 month since the last time, the following maintenance is to be executed.

### 8.1 Range check

If your flights during the last months have been in an area with compatible OGN receivers, and you had not opted out from OGN actively, you shall check your transmission range still is as at installation time with this tool: https://ktrax.kisstech.ch/flarm-liverange/.

astir13/SoftRF | User Manual v.1.3f rev.0 | pg. 17(19)

### 8.2 Internal Battery

Run an internal battery test:

- connect the main aircraft power supply battery,
- switch the SoftRF ”ON”, see 7.1.1,
- open the Status page as described in section 6.5,
- let the SoftRF charge the internal battery until it reads 4.1-4.2V in the SoftRF status page, if you have enabled WIFI power saving, you might require to read the battery voltage on the SoftRF display or restart the SoftRF to provide WIFI anew,
- disconnect external power, take the time and observe the battery voltage to decline slowly,
- when the SoftRF shuts down 10 minutes later (auto-power off), because the aircraft is not moving and on battery power (as described in section 7.1)
- switch the SoftRF ”ON” again, and reconnect to the status page, to read the Battery voltage: if the battery voltage is below 4.00 (Volt), the battery might need a capacity check and possibly replacement, see 6.6.
- if the battery voltage after the 10 minutes test is greater or equal 4.00 (Volt), the battery can be expected to keep up operations for at least 60 minutes when in flight

### 8.3 Firmware

- connect to the status page as described in section 8.2
- check https://github.com/astir13/SoftRF/wiki/Updates if there is a new Software Version for your device,
- in case there is a new firmware for your device and you decide the updates are relevant for your use, continue this list:
- continue on a PC (Mac, Linux, Windows are ok): download the new firmware for your device from https://github.com/astir13/SoftRF/wiki/Updates (you need internet connection for that), be careful to check that the two HW Revisions match the ones on the sticker of your SoftRF (T-Beam and astir13/SoftRF HW revision)
- disconnect from the internet WIFI,
- connect to the SoftRF WIFI,
- open the status page of the SoftRF,
- click on the button ”Firmware Update”,
- observe a new page opens called ”Firmware update”,
- click on ”Choose File” button,
- select the downloaded file name from your Download directory, it shall end with ”.bin”, if you downloaded a zip file, you might need to unzip it first to get to the ”.bin” file,
- observe the filename be shown besides the ”Choose File” button,
- click on the ”Update” button, to start the upload,

astir13/SoftRF | User Manual v.1.3f rev.0 | pg. 18(19)
- do not shut down power now!
- observe the update counter to count to 100, then wait for at least 3 minutes without taking power off the SoftRF,
- in case the counter stops for more than 60 seconds without update before reaching 100: wait 60 seconds more, then perform a power chip reset (see section 7.4 and retry;
- after above procedure, the SoftRF should restart and display the new firmware revision in the status page and on the built-in display
- run a functional test, see section 6.9.

## 9 Technical Data

### 9.1 Hard- and Software

The SoftRF is open source hardware and software. Please find the SoftRF firmware and hardware descriptions at http://github.com/astir13/SoftRF.

### 9.2 Transmit Spectral Purity and Power

For T-Beam HW revision 1.1, following transmit spectrum was recorded in EU power setting, which shows very good spectral cleanness and power below the maximum allowed +14dBm:


Figure 9: Transmit Spectrum of the T-Bone rev.1.1 Modem, used in astir13/SoftRF HW rev.1.0

### 9.3 General Data

Applicable for use with the ”Legacy” protocol (compatible with Flarm v6):

astir13/SoftRF | User Manual v.1.3f rev.0 | pg. 19(19)
Item | Value | Unit
Supply Voltage | 8-20 | V
typical supply current | 100 | mA
maximum supply current | 300 | mA
weight | 250 | g (including battery, antenna, power
| | switch, cabling and Flarm LED)
ambient temperature range | 0 - 40 | ◦C
battery type | 18650 Li-Ion | with protection
battery voltage typ. | 3.7 | V
max. | 4.2 | V
min. protection shut off | 3.1 | V
channel bandwidth | 125 | kHz
modulation type | 2-FSK
bitrate | 100 | kbps
max. transmit power | +14 | dBm in ”EU” setting
| +17 | dBm in ”FULL” setting
| +3 | dBm in ”LOW” setting
max. transmit duty cycle | < 1 | %
transmit frequency stability | +/-15 | kHz
GNSS chipset | uBlox NEO6M

## 10 License

Copyright (C) 2020-2021 Stefan Pielmeier (sp@symlinux.com)

Permission is granted to copy, distribute and/or modify this document under the terms of the GNU Free Documentation License, Version 1.3 or any later version published by the Free Software Foundation; with no Invariant Sections, no Front-Cover Texts, and no Back-Cover Texts. A copy of the license is included in the section entitled ”GNU Free Documentation License”.

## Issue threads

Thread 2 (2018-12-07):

no UART or Bluetooth data when GPS is lost

astir13, 2018-12-07:
Observed behaviour:
- the standalone edition stops transmitting any UART data when the GPS is lost.
- the PFLAU sentence is not sent out anymore
- therefore all connected equipment indicates loss of FLARM, where only loss of GPS is the problem

Reproduction:
- start SoftRF, let it get GPS and the prohibit GPS reception (go inside).

Preferred behaviour:
- I'd expect that UART data flow continues indicating loss of GPS at least in the PFLAU sentence

--------------------

## Hardware

- [x]   Prime Mark II
- [x]   Standalone
- [ ]   UAV

< photo of your hardware > (optional)

## Firmware version
https://github.com/astir13/SoftRF_standalone/commit/3deafedd0b14db367dfdf887e473f98229e6975c
## Firmware settings

Mode	0
Protocol	0
Band	1
Aircraft type	1
Alarm trigger	1
Tx Power	0
Volume	1
LED pointer	0
Bluetooth	0
NMEA GNSS	false
NMEA Private	true
NMEA Legacy	true
NMEA Sensors	true
NMEA Out	1
GDL90	0
DUMP1090	0
Stealth	false
No track	false

astir13, 2020-12-30:
this is not a problem on the prime mkII, and the standalone is not supported anymore.

Closed 2020-12-30.

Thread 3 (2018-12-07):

JDY-10 BT support

astir13, 2018-12-07:
--------------------

## Hardware

- [ ]   Prime Mark II
- [x]   Standalone
- [ ]   UAV

## Firmware version
https://github.com/astir13/SoftRF_standalone/commit/3deafedd0b14db367dfdf887e473f98229e6975c

## Firmware settings
Mode	0
Protocol	0
Band	1
Aircraft type	1
Alarm trigger	1
Tx Power	0
Volume	1
LED pointer	0
Bluetooth	0
NMEA GNSS	false
NMEA Private	true
NMEA Legacy	true
NMEA Sensors	true
NMEA Out	1
GDL90	0
DUMP1090	0
Stealth	false
No track	false

## Describe the bug (or ask a question)
adding JDY-10 BT support (using transmit in the blind)
- change default baud rate from 115200 to 38400
- change BT name
- change BT password to chosen via WebIF

## To Reproduce
N/A

## Expected behavior
JDY-10 shall work without additional out of circuit programming, i.e. show the right BT name, have 38400 UART speed and a custom BT code.

astir13, 2020-12-30:
not relevant anymore, the old SoftRF standalone 8266 based hardware is not used anymore in this fork.

Closed 2020-12-30.

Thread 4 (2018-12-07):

allow ICAO ID

astir13, 2018-12-07:
**ATTENTION** !

- Use this form to report bugs in released SoftRF firmware, hardware and web pages only ;
- Prior to asking a question, look into ["Closed issues"](https://github.com/lyusupov/SoftRF/issues?q=is%3Aissue+is%3Aclosed) area to see if it was answered before ;
- No any "ideas" or new feature requests, please ! New feature requests do not subject for taking into consideration unless they come from co-developers ;
- "Enhancements" of existing features are allowed only when you are ready to implement them by yourself ;

Recommended:
- screenshot or photo width - from 600 to 800 pixels ;
- aspect ratio - 4:3, 3:4, 16:9 or 9:16.
- substitute 'space' by 'x' character to mark a hardware checkbox

--------------------

## Hardware

- [ ]   Prime Mark II
- [ x]   Standalone
- [ ]   UAV

< photo of your hardware > (optional)

## Firmware version
https://github.com/astir13/SoftRF_standalone/commit/3deafedd0b14db367dfdf887e473f98229e6975c
<  screenshot of WebUI status page > (**required**)

## Firmware settings
Mode	0
Protocol	0
Band	1
Aircraft type	1
Alarm trigger	1
Tx Power	0
Volume	1
LED pointer	0
Bluetooth	0
NMEA GNSS	false
NMEA Private	true
NMEA Legacy	true
NMEA Sensors	true
NMEA Out	1
GDL90	0
DUMP1090	0
Stealth	false
No track	false
<  screenshot of WebUI settings page > (**required**)

## Describe the bug (or ask a question)
in the Web Config interface, it is not possible to program a custom ICAO ID overwriting the automatically generated ID of the SoftRF.

## To Reproduce
Start SoftRF, enter settings and observe that it is not possible to modify the ID

## Expected behavior
It shall be possible to enter a custom (ICAO) ID that is used after restart for the Device name (WIFI and BT) and on all air interface messages.

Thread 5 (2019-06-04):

Raspberry Pi Zero W with Lora HAT Dragino (SX1276)

pat-fly, 2019-06-04:
Hello
I set up the Raspberry Pi Zero W with the Dragino Lora HAT exactly the same as on the Wiki. I followed the steps downloading SoftRF and libraries and compiled.
When I start the program it says:

> $ cat /dev/ttyAMA0 | sudo ./SoftRF
> WARNING! Neither SX1276, CC13XX or NRF905 RFIC is detected!

I know there is a problem with serial ports on RPI3 due to bluetooth. But I switched it off and also I can get the GPS NMEA on /dev/ttySerial0. But I think this is not the problem of this error. So I went through checking the pin definitions and it looks okay. Everything like on the wiring picture of the wiki.
What am I doing wrong? What can I do to debug?

astir13, 2020-08-06:
Ok, better late than never: you posted your question to the SoftRF_standalone project, which is not supporting RPi, but only the standalone version (therefore the name ;-); sorry, I would suggest you go to the SoftRF project and follow the question/discussion rules there, maybe try to ask your question in the forum/discussion.

Closed 2020-08-06.

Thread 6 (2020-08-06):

External devices show high priority collision target not with relative course to my own course.

astir13, 2020-08-06:
When using the SoftRF with external devices, e.g. the Flarm LED display, that uses the PFLAU sentence only, the collision avoidance high priority target is not shown relative to my own (ThisAircraft) course but the bearing based on North.

Instead, it would be expected that such devices show the direction to the target as relative to our own (ThisAircraft) direction.

Closed 2020-08-06.

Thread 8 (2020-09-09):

Feature: Switch off when on battery and not in flight

astir13, 2020-09-09:
## Hardware

- [ ]   Standalone
- [x]   Prime Mark II
- [ ]   Dongle
- [ ]   SkyView EZ
- [ ]   Raspberry Edition
- [ ]   UAV
- [ ]   UAT978 module
- [ ]   Flight Recorder

## Requirement and background
(1) When the power for the instrument panel is removed on ground, or the main power supply switch shut off, the SoftRF shall also go into deep sleep to avoid draining the battery to cutoff level every time the plane is stowed in the hangar. It is too easy to forget shutting down individually the SoftRF manually. Most pilots are used to all instruments (also the ones with backup power) are sensing on the power line and on the flight state to shut down by themselfes (e.g. LX Navigation instruments do that really nicely).

(2) The pilot shall be able to indicate to the SoftRF "remotely", without touching the printed circut button, with a simple ON/OFF switch (not a button) if the user wants it on or off, on ground and during flight.

astir13, 2020-12-30:
done.

Closed 2020-12-30.

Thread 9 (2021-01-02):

Discharge to at least 50% when ext. power is off and not in air

astir13, 2021-01-02:
--------------------

## Hardware

- [x ]   Prime Mark II

## Firmware version

1.3e

## Firmware settings

Not relevant.

## Describe the feature
instead of only running 10 minutes after the external power goes down on ground (not in air), discharge the battery to 3.7V for LiPo/LiIon, as this is approx. 50% capacity for a normal cell and is a much more favorable storage voltage than "fully charged". This keeps the battery in better shape between usages.

## To Reproduce
N/A

## Expected behavior
See description.

astir13, 2021-05-02:
released as 1.3f on master.

Closed 2021-05-02.

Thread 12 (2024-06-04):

SoftRF cannot compile due to program memory full on ESP32: removed baro

VirusPilot, 2024-06-04:
I ran into the same issue with my fork and resolved it with selecting Partition Scheme -> Huge App (3MB no OTA/1MB SPIFFS). Linar still seems to compile with ESP32 version 1.0.5 while we compile with 2.0.17 which seems to consume much more memory. Moshe's fork is compiled with 2.0.3 which also needs less memory.

astir13, 2024-06-05:
Hey VirusPilot, thanks for the hint. Maybe the best solution would be to install 1.0.5 on the ESP?

VirusPilot, 2024-06-05:
I can give it a try with my fork this evening. My experience so far was that the combination of ESP32 Arduino Release Version and Arduino Library versions is very sensitive.

astir13, 2024-06-05:
Yeah, maybe we shouldn't change your solution if it works :-)
Did you verify v7 FLARM functionality already with the latest changes from Linar?

astir13, 2024-06-05:
"/Users/sp/Library/Arduino15/packages/esp32/tools/esptool_py/4.5.1/esptool" --chip esp32 --port "/dev/cu.usbserial-54760008741" --baud 921600  --before default_reset --after hard_reset write_flash  -z --flash_mode dio --flash_freq 80m --flash_size 4MB 0x1000 "/private/var/folders/84/m7fv_6sn4dz6y1qp31pwzf_80000gn/T/arduino/sketches/32954CF997E5E4A8A91CA0ADC4E5D6C9/SoftRF.ino.bootloader.bin" 0x8000 "/private/var/folders/84/m7fv_6sn4dz6y1qp31pwzf_80000gn/T/arduino/sketches/32954CF997E5E4A8A91CA0ADC4E5D6C9/SoftRF.ino.partitions.bin" 0xe000 "/Users/sp/Library/Arduino15/packages/esp32/hardware/esp32/2.0.16/tools/partitions/boot_app0.bin" 0x10000 "/private/var/folders/84/m7fv_6sn4dz6y1qp31pwzf_80000gn/T/arduino/sketches/32954CF997E5E4A8A91CA0ADC4E5D6C9/SoftRF.ino.bin"
esptool.py v4.5.1
Serial port /dev/cu.usbserial-54760008741
Connecting......
Chip is ESP32-D0WDQ6-V3 (revision v3.0)
Features: WiFi, BT, Dual Core, 240MHz, VRef calibration in efuse, Coding Scheme None
Crystal is 40MHz
MAC: 94:b5:55:c7:24:90
Uploading stub...
Running stub...
Stub running...
Changing baud rate to 921600
Changed.

A fatal error occurred: Unable to verify flash chip connection (Packet content transfer stopped (received 6 bytes)).
Failed uploading: uploading error: exit status 2

VirusPilot, 2024-06-05:
Yes, v7 FLARM works with latest upstream version.

VirusPilot, 2024-06-06:
So back to ESP32 Arduino Release Version 1.0.5 - it did not compile right away, I am afraid it is too old. So I can try newer versions to see how memory footprint changes.

VirusPilot, 2024-06-06:
So at least v2.0.3 (which is what Moshe's fork is using) seems to fit into the "Minimal SPIFFS" partition scheme, I haven't flashed that version yet:

_Sketch uses 1725445 bytes (87%) of program storage space. Maximum is 1966080 bytes.
Global variables use 60736 bytes (18%) of dynamic memory, leaving 266944 bytes for local variables. Maximum is 327680 bytes._

VirusPilot, 2024-10-08:
I ended up with v2.0.9 for the time being.

Closed 2024-10-08.

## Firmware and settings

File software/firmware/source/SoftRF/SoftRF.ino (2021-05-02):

/*
 * SoftRF(.ino) firmware
 * Copyright (C) 2016-2020 Linar Yusupov
 *
 * Author: Linar Yusupov, linar.r.yusupov@gmail.com
 *
 * Web: http://github.com/lyusupov/SoftRF
 *
 * Credits:
 *   Arduino core for ESP8266 is developed/supported by ESP8266 Community (support-esp8266@esp8266.com)
 *   AVR/Arduino nRF905 Library/Driver is developed by Zak Kemble, contact@zakkemble.co.uk
 *   flarm_decode is developed by Stanislaw Pusep, http://github.com/creaktive
 *   Arduino Time Library is developed by Paul Stoffregen, http://github.com/PaulStoffregen
 *   "Aircraft" and MAVLink Libraries are developed by Andy Little
 *   TinyGPS++ and PString Libraries are developed by Mikal Hart
 *   Adafruit NeoPixel Library is developed by Phil Burgess, Michael Miller and others
 *   TrueRandom Library is developed by Peter Knight
 *   IBM LMIC framework is maintained by Matthijs Kooijman
 *   ESP8266FtpServer is developed by David Paiva
 *   Lib_crc is developed by Lammert Bies
 *   OGN library is developed by Pawel Jalocha
 *   NMEA library is developed by Timur Sinitsyn, Tobias Simon, Ferry Huberts
 *   ADS-B encoder C++ library is developed by yangbinbin (yangbinbin_ytu@163.com)
 *   Arduino Core for ESP32 is developed by Hristo Gochkov
 *   ESP32 BT SPP library is developed by Evandro Copercini
 *   Adafruit BMP085 library is developed by Limor Fried and Ladyada
 *   Adafruit BMP280 library is developed by Kevin Townsend
 *   Adafruit MPL3115A2 library is developed by Limor Fried and Kevin Townsend
 *   U8g2 monochrome LCD, OLED and eInk library is developed by Oliver Kraus
 *   NeoPixelBus library is developed by Michael Miller
 *   jQuery library is developed by JS Foundation
 *   EGM96 data is developed by XCSoar team
 *   BCM2835 C library is developed by Mike McCauley
 *   SimpleNetwork library is developed by Dario Longobardi
 *   ArduinoJson library is developed by Benoit Blanchon
 *   Flashrom library is part of the flashrom.org project
 *   Arduino Core for TI CC13X0 is developed by Energia team
 *   EasyLink library is developed by Robert Wessels and Tony Cave
 *   Dump978 library is developed by Oliver Jowett
 *   FEC library is developed by Phil Karn
 *   AXP202X library is developed by Lewis He
 *   Arduino Core for STM32 is developed by Frederic Pillon
 *   TFT library is developed by Bodmer
 *
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
 * You should have received a copy of the GNU General Public License
 * along with this program.  If not, see <http://www.gnu.org/licenses/>.
 */

#include "OTAHelper.h"
#include "TimeHelper.h"
#include "LEDHelper.h"
#include "GNSSHelper.h"
#include "RFHelper.h"
#include "SoundHelper.h"
#include "EEPROMHelper.h"
#include "BatteryHelper.h"
#include "MAVLinkHelper.h"
#include "GDL90Helper.h"
#include "NMEAHelper.h"
#include "D1090Helper.h"
#include "SoCHelper.h"
#include "WiFiHelper.h"
#include "WebHelper.h"
#include "BaroHelper.h"
#include "TTNHelper.h"
#include "TrafficHelper.h"

#include "SoftRF.h"

#if defined(ENABLE_AHRS)
#include "AHRSHelper.h"
#endif /* ENABLE_AHRS */

#if LOGGER_IS_ENABLED
#include "LogHelper.h"
#endif /* LOGGER_IS_ENABLED */

#define DEBUG 0
#define DEBUG_TIMING 0

#define isTimeToDisplay() (millis() - LEDTimeMarker > 1000)
#define isTimeToExport() (millis() - ExportTimeMarker > 1000)
#define isTimeToShutdownBatNoMove() (millis() - ShutdownBatNoMove_timeMarker > 60000)

ufo_t ThisAircraft;
hardware_info_t hw_info = {
  .model    = SOFTRF_MODEL_STANDALONE,
  .revision = 0,
  .soc      = SOC_NONE,
  .rf       = RF_IC_NONE,
  .gnss     = GNSS_MODULE_NONE,
  .baro     = BARO_MODULE_NONE,
  .display  = DISPLAY_NONE
};

static unsigned long LEDTimeMarker = 0;
static unsigned long ExportTimeMarker = 0;
static unsigned long ShutdownBatNoMoveCnt = 0;
static unsigned long ShutdownBatNoMove_timeMarker = 0;

void setup()
{
  rst_info *resetInfo;

  hw_info.soc = SoC_setup(); // Has to be very first procedure in the execution order

  resetInfo = (rst_info *) SoC->getResetInfoPtr();

  Serial.begin(SERIAL_OUT_BR);

#if LOGGER_IS_ENABLED
  Logger_setup();
#endif /* LOGGER_IS_ENABLED */

  Serial.println();
  Serial.print(F(SOFTRF_IDENT));
  Serial.print(SoC->name);
  Serial.print(F(" FW.REV: " SOFTRF_FIRMWARE_VERSION " DEV.ID: "));
  Serial.println(String(SoC->getChipId(), HEX));
  Serial.println(F("Copyright (C) 2015-2020 Linar Yusupov. All rights reserved."));
  Serial.flush();

  Serial.println(""); Serial.print(F("Reset reason: ")); Serial.println(resetInfo->reason);
  Serial.println(SoC->getResetReason());
  Serial.print(F("Free heap size: ")); Serial.println(ESP.getFreeHeap());
#if defined(ESP32_DEVEL_CORE)
  Serial.print(F("PSRAM: ")); Serial.println(psramFound() ? F("found") : F("not found"));
#endif
  Serial.println(SoC->getResetInfo()); Serial.println("");

  EEPROM_setup();

  ThisAircraft.addr = SoC->getChipId() & 0x00FFFFFF;

  hw_info.rf = RF_setup();

  if (hw_info.model    == SOFTRF_MODEL_PRIME_MK2 &&
      hw_info.revision == 2                      &&
      RF_SX1276_RST_is_connected)
  {
    hw_info.revision = 5;
  }

  delay(100);

  hw_info.baro = Baro_setup();
#if defined(ENABLE_AHRS)
  hw_info.ahrs = AHRS_setup();
#endif /* ENABLE_AHRS */
  hw_info.display = SoC->Display_setup();

  if (settings->mode == SOFTRF_MODE_UAV) {
    Serial.begin(57600);
    MAVLink_setup();
    ThisAircraft.aircraft_type = AIRCRAFT_TYPE_UAV;
  }  else {
    hw_info.gnss = GNSS_setup();
    ThisAircraft.aircraft_type = settings->aircraft_type;
  }
  ThisAircraft.protocol = settings->rf_protocol;
  ThisAircraft.stealth  = settings->stealth;
  ThisAircraft.no_track = settings->no_track;

  Battery_setup();
  Traffic_setup();

  SoC->swSer_enableRx(false);

  LED_setup();

  WiFi_setup();

  if (SoC->Bluetooth) {
     SoC->Bluetooth->setup();
  }

  OTA_setup();
  Web_setup();
  NMEA_setup();

#if defined(ENABLE_TTN)
  TTN_setup();
#endif

  delay(1000);

  /* expedite restart on WDT reset */
  if (resetInfo->reason != REASON_WDT_RST) {
    LED_test();
  }

  SoC->Sound_test(resetInfo->reason);

  switch (settings->mode)
  {
  case SOFTRF_MODE_TXRX_TEST:
  case SOFTRF_MODE_WATCHOUT:
    Time_setup();
    break;
  case SOFTRF_MODE_BRIDGE:
    break;
  case SOFTRF_MODE_NORMAL:
  case SOFTRF_MODE_UAV:
  default:
    SoC->swSer_enableRx(true);
    break;
  }

  SoC->WDT_setup();
}

void loop()
{
  // Do common RF stuff first
  RF_loop();

  switch (settings->mode)
  {
  case SOFTRF_MODE_TXRX_TEST:
    txrx_test_loop();
    break;
  case SOFTRF_MODE_UAV:
    uav_loop();
    break;
  case SOFTRF_MODE_BRIDGE:
    bridge_loop();
    break;
  case SOFTRF_MODE_WATCHOUT:
    watchout_loop();
    break;
  case SOFTRF_MODE_NORMAL:
  default:
    normal_loop();
    break;
  }

  // Show status info on tiny OLED display
  SoC->Display_loop();

  // battery status LED
  LED_loop();

  // Handle DNS
  WiFi_loop();

  // Handle Web
  Web_loop();

  // Handle OTA update.
  OTA_loop();

#if LOGGER_IS_ENABLED
  Logger_loop();
#endif /* LOGGER_IS_ENABLED */

  SoC->loop();

  // shut down if battery voltage is too low
  Battery_loop();

#if defined (SOFTRF_SHUTDOWN_BAT_NO_MOVE)
  // if no external voltage and speed < 10kt:
  // shut down when battery reaches 50% (ca. 3.7V), but not earlier
  // than 10 minutes; LiPo/LiIon storage is best done at 50% =>
  // if shut down for longer periods, use this method to ensure proper
  // LiIon storage ;-)
  if (isTimeToShutdownBatNoMove()) {
    if (! SoC->onExternalPower() && ThisAircraft.speed < 10) {
      ShutdownBatNoMoveCnt++;
    } else {
      ShutdownBatNoMoveCnt = 0;
    }
    if (ShutdownBatNoMoveCnt > 10) {
      if (Battery_voltage() < Battery_50perc()) {
        shutdown("Pwr Save.");
      }
    }
    ShutdownBatNoMove_timeMarker = millis();
  }
#endif /* SOFTRF_SHUTDOWN_BAT_NO_MOVE */

  yield();
}

void shutdown(const char *msg)
{
  SoC->WDT_fini();

  SoC->swSer_enableRx(false);

  NMEA_fini();

  Web_fini();

  WiFi_fini();

  if (settings->mode != SOFTRF_MODE_UAV) {
    GNSS_fini();
  }

  SoC->Display_fini(msg);

  RF_Shutdown();

  SoC_fini();
}

void normal_loop()
{
  bool success;

  Baro_loop();

#if defined(ENABLE_AHRS)
  AHRS_loop();
#endif /* ENABLE_AHRS */

  PickGNSSFix();

  GNSSTimeSync();

  ThisAircraft.timestamp = now();
  if (isValidFix()) {
    ThisAircraft.latitude = gnss.location.lat();
    ThisAircraft.longitude = gnss.location.lng();
    ThisAircraft.altitude = gnss.altitude.meters();
    ThisAircraft.course = gnss.course.deg();
    ThisAircraft.speed = gnss.speed.knots();
    ThisAircraft.hdop = (uint16_t) gnss.hdop.value();
    ThisAircraft.geoid_separation = gnss.separation.meters();

    /*
     * When geoidal separation is zero or not available - use approx. EGM96 value
     */
    if (ThisAircraft.geoid_separation == 0.0) {
      ThisAircraft.geoid_separation = (float) LookupSeparation(
                                                ThisAircraft.latitude,
                                                ThisAircraft.longitude
                                              );
      /* we can assume the GPS unit is giving ellipsoid height */
      ThisAircraft.altitude -= ThisAircraft.geoid_separation;
    }

    RF_Transmit(RF_Encode(&ThisAircraft), true);
  }

  success = RF_Receive();

#if DEBUG
  success = true;
#endif

  if (success && isValidFix()) ParseData();

#if defined(ENABLE_TTN)
  TTN_loop();
#endif

  if (isValidFix()) {
    Traffic_loop();
  }

  if (isTimeToDisplay()) {
    if (isValidFix()) {
      LED_DisplayTraffic();
    } else {
      LED_Clear();
    }
    LEDTimeMarker = millis();
  }

  if (isTimeToExport()) {
    NMEA_Export();

#if defined(ENABLE_GPS_NMEA_OUT)
    if (isValidFix()) {
      GDL90_Export();
      D1090_Export();
    }
#endif
    ExportTimeMarker = millis();
  }

  // Handle Air Connect
  NMEA_loop();

  ClearExpired();

}

void uav_loop()
{
  bool success = false;

  PickMAVLinkFix();

  MAVLinkTimeSync();
  MAVLinkSetWiFiPower();

  ThisAircraft.timestamp = now();

  if (isValidMAVFix()) {
    ThisAircraft.latitude = the_aircraft.location.gps_lat / 1e7;
    ThisAircraft.longitude = the_aircraft.location.gps_lon / 1e7;
    ThisAircraft.altitude = the_aircraft.location.gps_alt / 1000.0;
    ThisAircraft.course = the_aircraft.location.gps_cog;
    ThisAircraft.speed = (the_aircraft.location.gps_vog / 100.0) / _GPS_MPS_PER_KNOT;
    ThisAircraft.pressure_altitude = the_aircraft.location.baro_alt;
    ThisAircraft.hdop = the_aircraft.location.gps_hdop;

    RF_Transmit(RF_Encode(&ThisAircraft), true);
  }

  success = RF_Receive();

  if (success && isValidMAVFix()) ParseData();

  if (isTimeToExport() && isValidMAVFix()) {
    MAVLinkShareTraffic();
    ExportTimeMarker = millis();
  }

  ClearExpired();
}

void bridge_loop()
{
  bool success;

  size_t tx_size = Raw_Receive_UDP(&TxBuffer[0]);

  if (tx_size > 0) {
    RF_Transmit(tx_size, true);
  }

  success = RF_Receive();

  if(success)
  {
    size_t rx_size = RF_Payload_Size(settings->rf_protocol);
    rx_size = rx_size > sizeof(fo.raw) ? sizeof(fo.raw) : rx_size;

    memset(fo.raw, 0, sizeof(fo.raw));
    memcpy(fo.raw, RxBuffer, rx_size);

    if (settings->nmea_p) {
      StdOut.print(F("$PSRFI,"));
      StdOut.print((unsigned long) now());    StdOut.print(F(","));
      StdOut.print(Bin2Hex(fo.raw, rx_size)); StdOut.print(F(","));
      StdOut.println(RF_last_rssi);
    }

    Raw_Transmit_UDP();
  }

  if (isTimeToDisplay()) {
    LED_Clear();
    LEDTimeMarker = millis();
  }
}

void watchout_loop()
{
  bool success;

  success = RF_Receive();

  if (success) {
    size_t rx_size = RF_Payload_Size(settings->rf_protocol);
    rx_size = rx_size > sizeof(fo.raw) ? sizeof(fo.raw) : rx_size;

    memset(fo.raw, 0, sizeof(fo.raw));
    memcpy(fo.raw, RxBuffer, rx_size);

    if (settings->nmea_p) {
      StdOut.print(F("$PSRFI,"));
      StdOut.print((unsigned long) now());    StdOut.print(F(","));
      StdOut.print(Bin2Hex(fo.raw, rx_size)); StdOut.print(F(","));
      StdOut.println(RF_last_rssi);
    }
  }

  if (isTimeToDisplay()) {
    LED_Clear();
    LEDTimeMarker = millis();
  }
}

unsigned int pos_ndx = 0;
unsigned long TxPosUpdMarker = 0;

void txrx_test_loop()
{
  bool success = false;
#if DEBUG_TIMING
  unsigned long baro_start_ms, baro_end_ms;
  unsigned long tx_start_ms, tx_end_ms, rx_start_ms, rx_end_ms;
  unsigned long parse_start_ms, parse_end_ms, led_start_ms, led_end_ms;
  unsigned long export_start_ms, export_end_ms;
  unsigned long oled_start_ms, oled_end_ms;
#endif
  ThisAircraft.timestamp = now();

  if (TxPosUpdMarker == 0 || (millis() - TxPosUpdMarker) > 4000 ) {
    ThisAircraft.latitude =  pgm_read_float( &txrx_test_positions[pos_ndx][0]);
    ThisAircraft.longitude =  pgm_read_float( &txrx_test_positions[pos_ndx][1]);
    pos_ndx = (pos_ndx + 1) % TXRX_TEST_NUM_POSITIONS;
    TxPosUpdMarker = millis();
  }
  ThisAircraft.altitude = TXRX_TEST_ALTITUDE;
  ThisAircraft.course = TXRX_TEST_COURSE;
  ThisAircraft.speed = TXRX_TEST_SPEED;
  ThisAircraft.vs = TXRX_TEST_VS;

#if DEBUG_TIMING
  baro_start_ms = millis();
#endif
  Baro_loop();
#if DEBUG_TIMING
  baro_end_ms = millis();
#endif

#if defined(ENABLE_AHRS)
  AHRS_loop();
#endif /* ENABLE_AHRS */

#if DEBUG_TIMING
  tx_start_ms = millis();
#endif
  RF_Transmit(RF_Encode(&ThisAircraft), true);
#if DEBUG_TIMING
  tx_end_ms = millis();
  rx_start_ms = millis();
#endif
  success = RF_Receive();
#if DEBUG_TIMING
  rx_end_ms = millis();
#endif

#if DEBUG_TIMING
  parse_start_ms = millis();
#endif
  if (success) ParseData();
#if DEBUG_TIMING
  parse_end_ms = millis();
#endif

#if defined(ENABLE_TTN)
  TTN_loop();
#endif

  Traffic_loop();

#if DEBUG_TIMING
  led_start_ms = millis();
#endif
  if (isTimeToDisplay()) {
    LED_DisplayTraffic();
    LEDTimeMarker = millis();
  }
#if DEBUG_TIMING
  led_end_ms = millis();
#endif

#if DEBUG_TIMING
  export_start_ms = millis();
#endif
  if (isTimeToExport()) {
    NMEA_Position();
    NMEA_Export();
    GDL90_Export();
    D1090_Export();
    ExportTimeMarker = millis();
  }
#if DEBUG_TIMING
  export_end_ms = millis();
#endif

#if DEBUG_TIMING
  oled_start_ms = millis();
#endif
//  SoC->Display_loop();
#if DEBUG_TIMING
  oled_end_ms = millis();
#endif

#if DEBUG_TIMING
  if (baro_start_ms - baro_end_ms) {
    Serial.print(F("Baro start: "));
    Serial.print(baro_start_ms);
    Serial.print(F(" Baro stop: "));
    Serial.println(baro_end_ms);
  }
  if (tx_end_ms - tx_start_ms) {
    Serial.print(F("TX start: "));
    Serial.print(tx_start_ms);
    Serial.print(F(" TX stop: "));
    Serial.println(tx_end_ms);
  }
  if (rx_end_ms - rx_start_ms) {
    Serial.print(F("RX start: "));
    Serial.print(rx_start_ms);
    Serial.print(F(" RX stop: "));
    Serial.println(rx_end_ms);
  }
  if (parse_end_ms - parse_start_ms) {
    Serial.print(F("Parse start: "));
    Serial.print(parse_start_ms);
    Serial.print(F(" Parse stop: "));
    Serial.println(parse_end_ms);
  }
  if (led_end_ms - led_start_ms) {
    Serial.print(F("LED start: "));
    Serial.print(led_start_ms);
    Serial.print(F(" LED stop: "));
    Serial.println(led_end_ms);
  }
  if (export_end_ms - export_start_ms) {
    Serial.print(F("Export start: "));
    Serial.print(export_start_ms);
    Serial.print(F(" Export stop: "));
    Serial.println(export_end_ms);
  }
  if (oled_end_ms - oled_start_ms) {
    Serial.print(F("OLED start: "));
    Serial.print(oled_start_ms);
    Serial.print(F(" OLED stop: "));
    Serial.println(oled_end_ms);
  }
#endif

  // Handle Air Connect
  NMEA_loop();

  ClearExpired();
}

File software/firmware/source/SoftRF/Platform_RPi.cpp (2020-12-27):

/*
 * Platform_RPi.cpp
 * Copyright (C) 2018-2020 Linar Yusupov
 *
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
 * You should have received a copy of the GNU General Public License
 * along with this program.  If not, see <http://www.gnu.org/licenses/>.
 */

/*
 * Usage example:
 *
 *  pi@raspberrypi $ make -f Makefile.RPi
 *
 *     < ... skipped ... >
 *
 *  pi@raspberrypi $ { echo "{class:SOFTRF,protocol:OGNTP}" ; cat /dev/ttyUSB0 ; } | sudo ./SoftRF
 *  SX1276 RFIC is detected.
 *  $GPGSA,A,3,02,30,05,06,07,09,,,,,,,5.09,3.19,3.97*04
 *  $GPRMC,145750.00,A,5XXX.XXX68,N,03XXX.XXX33,E,0.701,,051118,,,A*7E
 *  $GPGGA,145750.00,5XXX.XXX68,N,03XXX.XXX33,E,1,06,3.19,179.2,M,12.5,M,,*5E
 *  $PFLAA,3,0,0,0,2,C5D804!OGN_C5D804,0,,0,00000.0,1*60
 *  $PFLAU,1,1,2,1,3,-30,2,0,0*4E
 *
 *     < ... skipped ... >
 *
 *  Concurrent shell session:
 *
 *  pi@raspberrypi $ ps -ax | grep dump1090
 *  2381 pts/1    Sl+    1:53 dump1090 --interactive --net
 *
 *  pi@raspberrypi $ wget -q -O - http://localhost:8080/data/aircraft.json | nc -N localhost 30007
 *
 */

#if defined(RASPBERRY_PI)

#include "Platform_RPi.h"
#include "SoCHelper.h"
#include "EEPROMHelper.h"
#include <TinyGPS++.h>
#include <aircraft.h>
#include "RFHelper.h"
#include "LEDHelper.h"
#include "SoundHelper.h"
#include "BaroHelper.h"
#include "TrafficHelper.h"
#include "NMEAHelper.h"
#include "GDL90Helper.h"
#include "D1090Helper.h"
#include "JSONHelper.h"
#include "WiFiHelper.h"
#include "EPDHelper.h"
#include "BatteryHelper.h"

#include "TCPServer.h"

#include <stdio.h>
#include <sys/select.h>

#include <iostream>

#include <ArduinoJson.h>

// Dragino LoRa/GPS HAT or compatible SX1276 pin mapping
lmic_pinmap lmic_pins = {
    .nss = SOC_GPIO_PIN_SS,
    .rxtx = { LMIC_UNUSED_PIN, LMIC_UNUSED_PIN },
    .rst = SOC_GPIO_PIN_RST,
#if !defined(USE_OGN_RF_DRIVER)
    .dio = {LMIC_UNUSED_PIN, LMIC_UNUSED_PIN, LMIC_UNUSED_PIN},
#else
    .dio = {SOC_GPIO_PIN_DIO0, LMIC_UNUSED_PIN, LMIC_UNUSED_PIN},
#endif
};

TTYSerial Serial1("/dev/ttyAMA0");
TTYSerial Serial2("/dev/ttyUSB0");

// These callbacks are only used in over-the-air activation, so they are
// left empty here (we cannot leave them out completely unless
// DISABLE_JOIN is set in config.h, otherwise the linker will complain).
void os_getArtEui (u1_t* buf) { }
void os_getDevEui (u1_t* buf) { }
void os_getDevKey (u1_t* buf) { }

void onEvent (ev_t ev) { }

eeprom_t eeprom_block;
settings_t *settings = &eeprom_block.field.settings;
ufo_t ThisAircraft;
aircraft the_aircraft;

char UDPpacketBuffer[UDP_PACKET_BUFSIZE]; // buffer to hold incoming and outgoing packets

hardware_info_t hw_info = {
  .model    = SOFTRF_MODEL_RASPBERRY,
  .revision = 0,
  .soc      = SOC_NONE,
  .rf       = RF_IC_NONE,
  .gnss     = GNSS_MODULE_NONE,
  .baro     = BARO_MODULE_NONE,
  .display  = DISPLAY_NONE
};

#define isTimeToExport() (millis() - ExportTimeMarker > 1000)
unsigned long ExportTimeMarker = 0;

std::string input_line;

TCPServer Traffic_TCP_Server;

//-------------------------------------------------------------------------
//
// The MIT License (MIT)
//
// Copyright (c) 2015 Andrew Duncan
//
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
//-------------------------------------------------------------------------

#include <fcntl.h>
#include <inttypes.h>
#include <stdint.h>
#include <stdlib.h>
#include <string.h>
#include <unistd.h>

#include <sys/ioctl.h>

static uint32_t SerialNumber = 0;

void RPi_SerialNumber(void)
{
    int fd = open("/dev/vcio", 0);
    if (fd == -1)
    {
        perror("open /dev/vcio");
        exit(EXIT_FAILURE);
    }

    uint32_t property[32] =
    {
        0x00000000,
        0x00000000,
        0x00010004,
        0x00000010,
        0x00000000,
        0x00000000,
        0x00000000,
        0x00000000,
        0x00000000,
        0x00000000
    };

    property[0] = 10 * sizeof(property[0]);

    if (ioctl(fd, _IOWR(100, 0, char *), property) == -1)
    {
        perror("ioctl");
        exit(EXIT_FAILURE);
    }

    close(fd);

    SerialNumber = property[5];
}

//----- end of MIT License ------------------------------------------------

static void RPi_setup()
{
  eeprom_block.field.magic                  = SOFTRF_EEPROM_MAGIC;
  eeprom_block.field.version                = SOFTRF_EEPROM_VERSION;
  eeprom_block.field.settings.mode          = SOFTRF_MODE_NORMAL;
  eeprom_block.field.settings.rf_protocol   = RF_PROTOCOL_OGNTP;
  eeprom_block.field.settings.band          = RF_BAND_EU;
  eeprom_block.field.settings.aircraft_type = AIRCRAFT_TYPE_GLIDER;
  eeprom_block.field.settings.txpower       = RF_TX_POWER_FULL;
  eeprom_block.field.settings.volume        = BUZZER_VOLUME_FULL;
  eeprom_block.field.settings.pointer       = DIRECTION_NORTH_UP;
  eeprom_block.field.settings.bluetooth     = BLUETOOTH_OFF;
  eeprom_block.field.settings.alarm         = TRAFFIC_ALARM_DISTANCE;

  eeprom_block.field.settings.nmea_g        = true;
  eeprom_block.field.settings.nmea_p        = false;
  eeprom_block.field.settings.nmea_l        = true;
  eeprom_block.field.settings.nmea_s        = true;
  eeprom_block.field.settings.nmea_out      = NMEA_UART;
  eeprom_block.field.settings.gdl90         = GDL90_OFF;
  eeprom_block.field.settings.d1090         = D1090_OFF;
  eeprom_block.field.settings.json          = JSON_OFF;
  eeprom_block.field.settings.stealth       = false;
  eeprom_block.field.settings.no_track      = false;
  eeprom_block.field.settings.power_save    = POWER_SAVE_NONE;

  RPi_SerialNumber();
}

static void RPi_loop()
{

}

static void RPi_fini()
{

}

static void RPi_reset()
{

}

static uint32_t RPi_getChipId()
{
  return SerialNumber ? SerialNumber : gethostid();
}

static long RPi_random(long howsmall, long howBig)
{
  return random(howsmall, howBig);
}

static void RPi_WiFi_transmit_UDP(int port, byte *buf, size_t size)
{
  /* TBD */
}

static void RPi_SPI_begin()
{
  SPI.begin();
}

static void RPi_swSer_begin(unsigned long baud)
{
  swSer.begin(baud);
}

static byte RPi_Display_setup()
{
  byte rval = DISPLAY_NONE;

  if (EPD_setup()) {
    rval = DISPLAY_EPD_2_7;
  }

  return rval;
}

static void RPi_Display_loop()
{
  if (hw_info.display == DISPLAY_EPD_2_7) {
    EPD_loop();
  }
}

static void RPi_Display_fini(const char *msg)
{

}

void RPi_GNSS_PPS_Interrupt_handler() {
  PPS_TimeMarker = millis();
}

static unsigned long RPi_get_PPS_TimeMarker() {
  return PPS_TimeMarker;
}

static void RPi_UATSerial_begin(unsigned long baud)
{
  UATSerial.begin(baud);
  UATSerial.dtr(false);
  UATSerial.rts(false);
}

static void RPi_CC13XX_restart()
{
  UATSerial.dtr(false);

  delay(100);

#if DEBUG
  Serial.println("RTS on");
#endif

  UATSerial.rts(true);

  delay(100);

#if DEBUG
  Serial.println("RTS off");
#endif

  UATSerial.rts(false);
}

static void RPi_WDT_setup()
{
  /* TBD */
}

static void RPi_WDT_fini()
{
  /* TBD */
}
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

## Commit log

2018-11-23 improved debug printout for channel/frequency nRF905
2018-11-24 Revert "else is only reached when RF_ready is true, so why setting it to true then?" because I saw this wrong, mixed it up with the if below.
    This reverts commit d5d2b140165fdc3439d825ef7e9aadc2129dc777.
    [RFHelper.cpp]
2020-03-15 - debug printout of RF_SetChannel
2020-03-15 PFLAV timer needs resetting
    [NMEAHelper.cpp]
2020-03-19 + write TX to UART when transmitting
2020-03-19 filter GSV and GSA out of the NMEA stream, is redundant
2020-03-19 change default AP Adress to avoid conflicts
    [WiFiHelper.cpp]
2020-04-05 disable NMEA_TCP_SERVICE to avoid GSA sentence
    [Platform_ESP32.h]
2020-04-05 disable GLL, GSV, VTG and GSA sentences on ublox gps to avoid overflow (I see GPS sentences scrambled and the device loosing GPS even though the GPS LED indicating PPS is flashing
    [GNSSHelper.cpp]
2020-04-05 NMEA out filtering for GS* sentences not needed anymore
2020-08-06 PFLAU bearing relative to own to get correct direction on Flarm LED
    [NMEAHelper.cpp]
2020-09-14 v1.3:corrected LAC, option for UART out to Serial and BT
    [NMEAHelper.cpp, Platform_ESP32.cpp, SoftRF.h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]
2020-09-21 show batt voltage on OLED
2020-09-21 battery voltage, off switch added
2020-10-17 1.3c:power off is always a full power off
2020-12-27 1.3d:+SOFTRF_SHUTDOWN_BAT_NO_MOVE: allow to shut down softrf if no external power and speed < 10kt for > 10 minutes.
2020-12-27 change charge target for ESP32 to be 4.1V
2020-12-28 Web:add info abt. astir13 fork (to avoid Linar getting reported problems from my bugs)
    [WebHelper.cpp]
2020-12-28 was missing from 1.3d commit to add auto-power off on battery
    [Platform_STM32.cpp]
2020-12-30 1.3e:EU power option for 14dBm max
2021-01-02 auto power off w/o external power discharges to 3.7V on lipo
2021-01-28 schematic added for the SoftRF in its environment
2021-05-02 deleted SoftRF cases, not used for this design
    [Lilygo_TTGO_V1.1_case_v9.f3d, SkyView-Case-EZ-Body-plus.stl, SkyView-Case-EZ-Body.stl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]
2022-03-25 + a label to be used with the powerswitch
